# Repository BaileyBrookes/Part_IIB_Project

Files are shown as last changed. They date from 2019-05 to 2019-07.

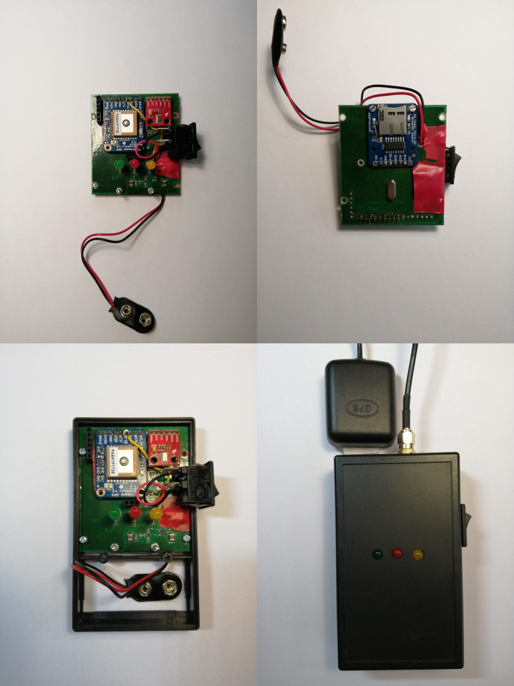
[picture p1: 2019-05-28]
Final Report/Module.png

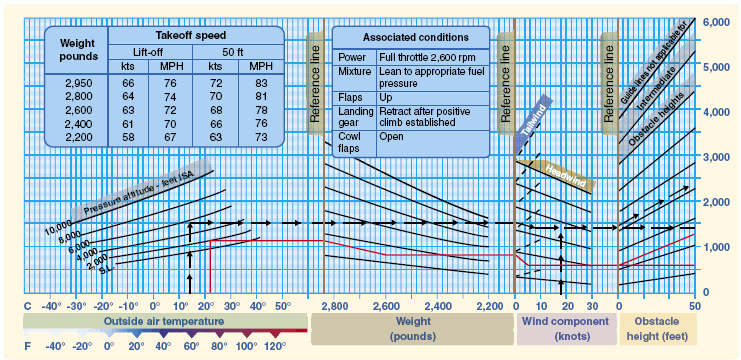
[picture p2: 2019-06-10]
Final Report/Performance_chart.png

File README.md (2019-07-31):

# Part IIB Project: Aircraft Performance Logger:
### Developing a cheap module using GPS and pressure sensor to measure accurately take-off distance required (TODR)
This is the enire project directory, files/folders of note are:

1. AircraftDataLogger - KiCad design files for PCB design

2. \Code\Arduino Sketches\Firmware - Firmware for the PCB

3. Code\TODR.py - Python script that calculates TODR and ground roll

4. Code\CheapDGPS2.py - Script investigating the DGPS idea, with data collected in preliminary testing

Other python scripts have been used in investigation and making plots.

For any clarification or help please email me at bailey.brookes@hotmail.co.uk

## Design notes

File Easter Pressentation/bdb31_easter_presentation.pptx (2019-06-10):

## Aircraft Performance Logger

IIB Project – Easter Presentation

## Problem definition

- Performance characteristics of airplanes:
  - Ground roll
  - Distance to clear 15 m = Take off distance required (TODR)
- Accurate data for safety, creation of performance charts
- Current methods:
  - Expensive DGPS, image processing or laser systems
  - By-eye by test pilots
- Want a cheap module separate from aircraft.

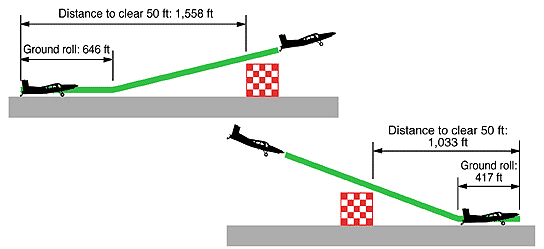
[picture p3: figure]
A close up of text on a white background Description generated with high confidence

Ground roll and TODR definitions

A screenshot of text Description generated with high confidence

Performance chart example

## Project Plan

- Michaelmas – Proof of concept

- Charactise GPS and pressure sensor
- Explore ways to make GPS readings more accurate
- Decide on method of measuring distance and altitude going forward
- Choose method of controlling electronics
- Choose data processing method

- Lent – Design, Build

- Design PCB
- Assembly PCB and module
- Program microcontroller

Easter – Test, Write up

- Testing
  - Static
  - Flight
- Write up

## ‘Cheap’ DGPS

- Errors in readings due to multipath, ionosphere, reflection of signals, etc
- Corrections usually done on signals themselves
- Blue ‘base’ readings, average is true location
- Pair each ‘base’ reading to red ‘roaming’ reading
- Find orange error vector between base reading and average
- Subtract from red roaming to correct it

Longitude

Latitude

## Results: ‘Cheap’ DGPS doesn’t work

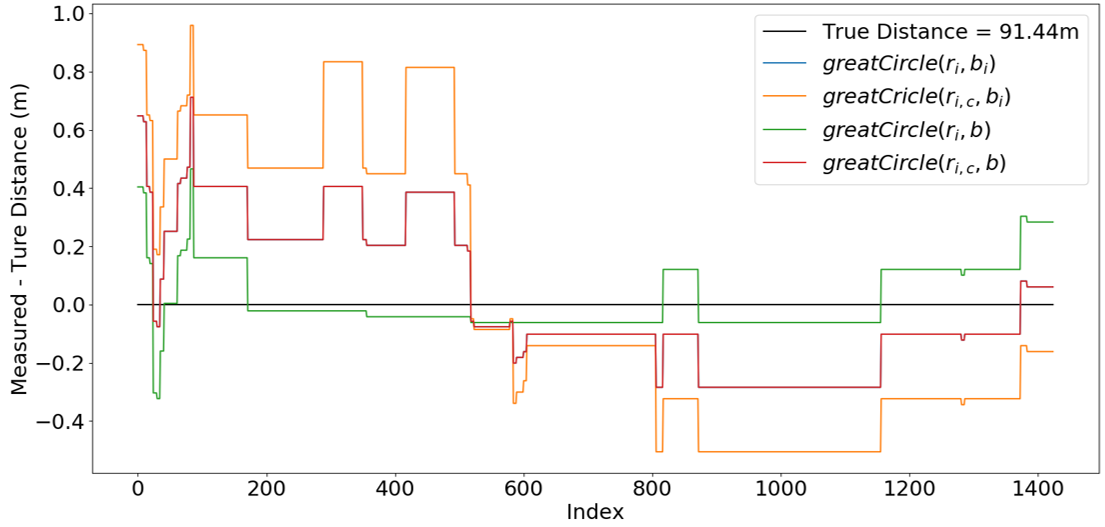
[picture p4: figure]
A close up of a map Description generated with very high confidence

‘100m Test’ True distance = 91.44m | Distance Delta (m) | MSE (m²) | σ (m)
Uncorrected | 1.3602 | 0.0632 | 0.2507
Corrected | 1.3602 | 0.2246 | 0.4734

## Results: The Module

A picture containing wall, indoor Description generated with very high confidence

Final Module

LED

LED

LED

GPS Module

UART

Microcontroller

Pressure Sensor

I2C

Switch

SPI

SD Card

Block diagram of design

## Results: Calculating TODR

1. The run data of distance vs height is plotted.
2. Assuming a linear rate of climb, the line of best fit for the climbing phase is calculated.
3. This line is extended for the entire run (orange line).
4. The average height for the runway is plotted and extended for the length of the whole run (green line).

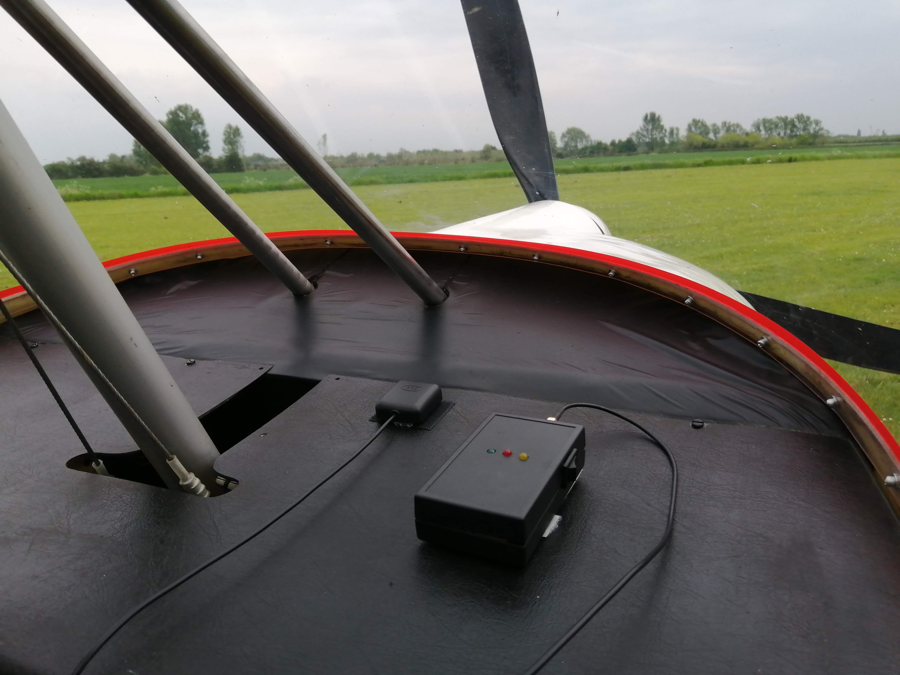
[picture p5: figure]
A small plane sitting on a runway Description generated with very high confidence
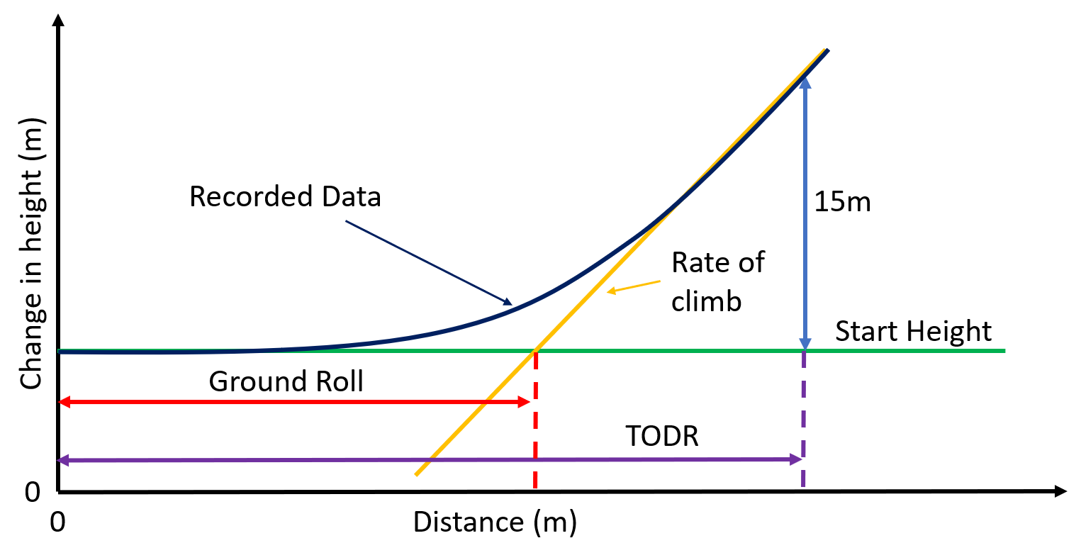
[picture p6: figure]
A picture containing sitting, indoor Description generated with high confidence

## Results: TODR and Ground Roll

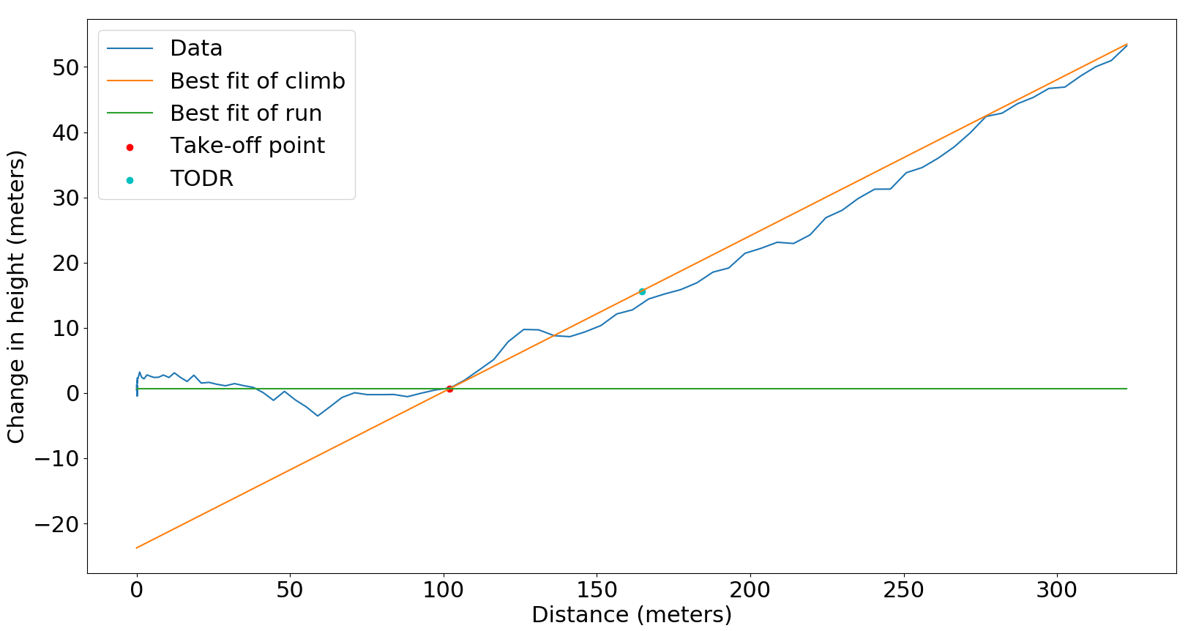
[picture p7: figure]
A close up of a map Description generated with high confidence

3.2m jump

Ground Roll: 101.91m

TODR : 164.58 m

Handbook value : 195 m

## Results: Effect of propeller wash

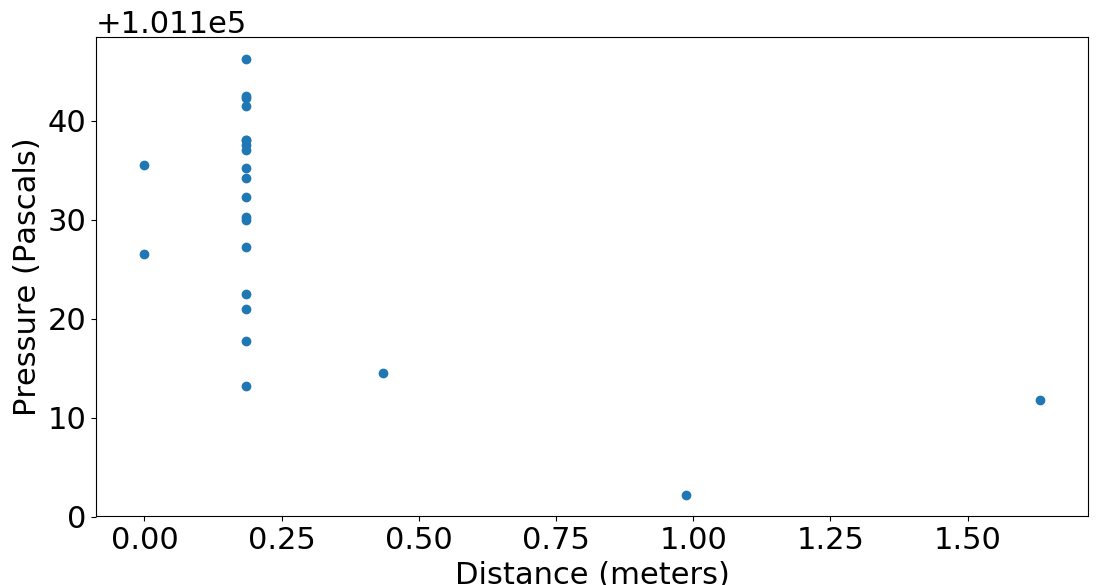
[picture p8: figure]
A screenshot of a cell phone Description generated with very high confidence

(dh)/(dp)=1/(−ρh)=1/(−1.644 ∗9.81)=−0.00875 m/Pa
∆p=33 Pa ∴ ∆h=2.89m ±0.8m

Propeller speed increased as take-off starts
Increased airspeed through propeller means lower pressure
Causes an apparent jump in height

p_1 + 1/2ρv_1^2 = p_2 + 1/2ρv_2^2
p_2 −p_1 = 1/2ρ(v_1^2 −v_2^2 )
v_2 >v_1 ⇒p_2 <p_1

## Conclusions

- ‘Cheap’ DGPS not used as no improvement on accuracy
- Method of calculating TODR sometimes overestimates take off point
- Pressure sensor accuracy less than desired due to
  - Oversampling rate
  - Propeller wash
  - Dynamic effects
- Module, with further development, can measure other parameters, such as landing

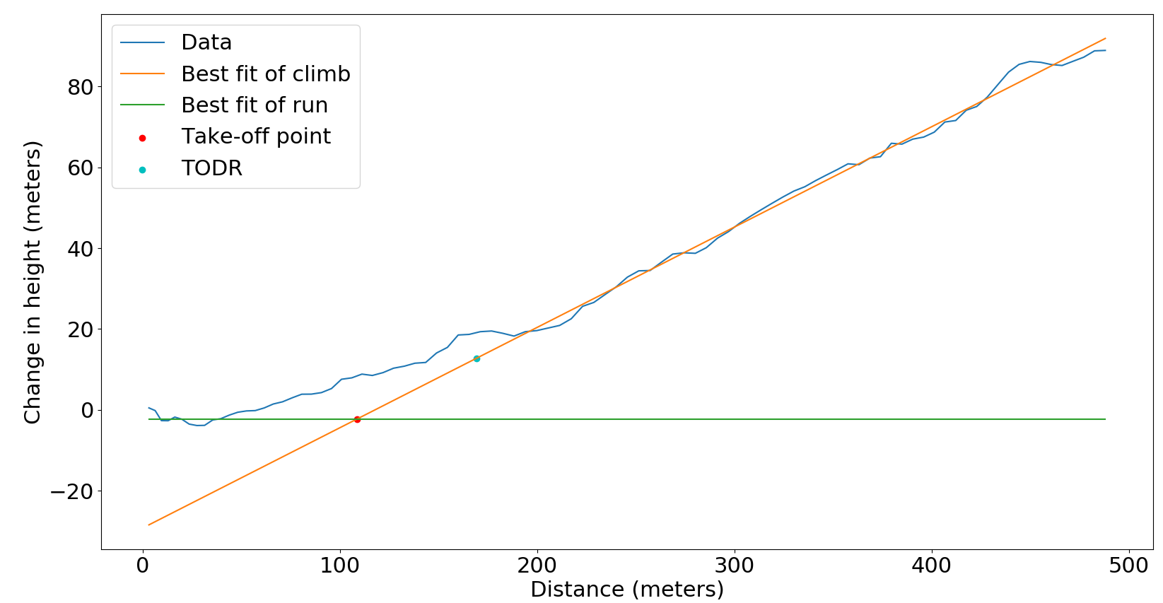
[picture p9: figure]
A close up of a map Description generated with very high confidence
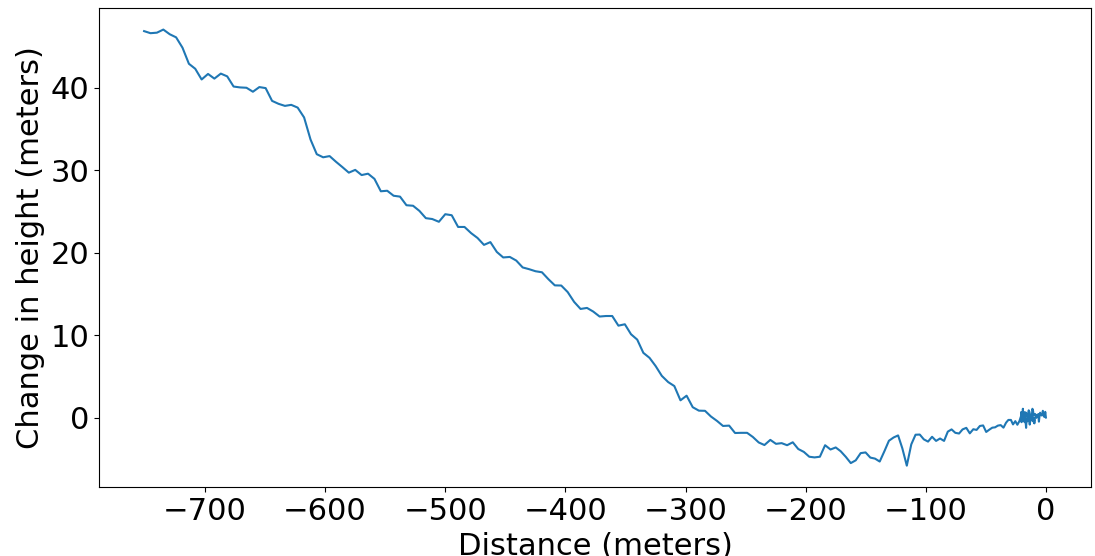
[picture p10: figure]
A screenshot of a cell phone Description generated with very high confidence

## Aircraft Performance Logger

IIB Project – Easter Presentation

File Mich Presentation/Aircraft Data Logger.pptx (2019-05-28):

## Aircraft Data Logger

IIB Project – Michaelmas Presentation

## Can you land here?

London City Airport (LYC): 1,508m

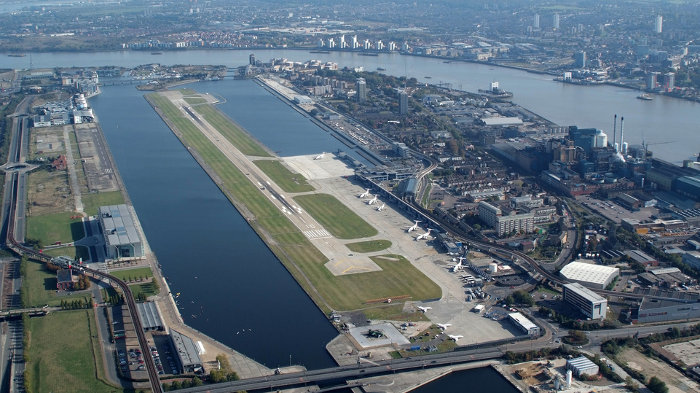
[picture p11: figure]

Barra Airport (BRR): 680,799,846m
- Sand
- Tide

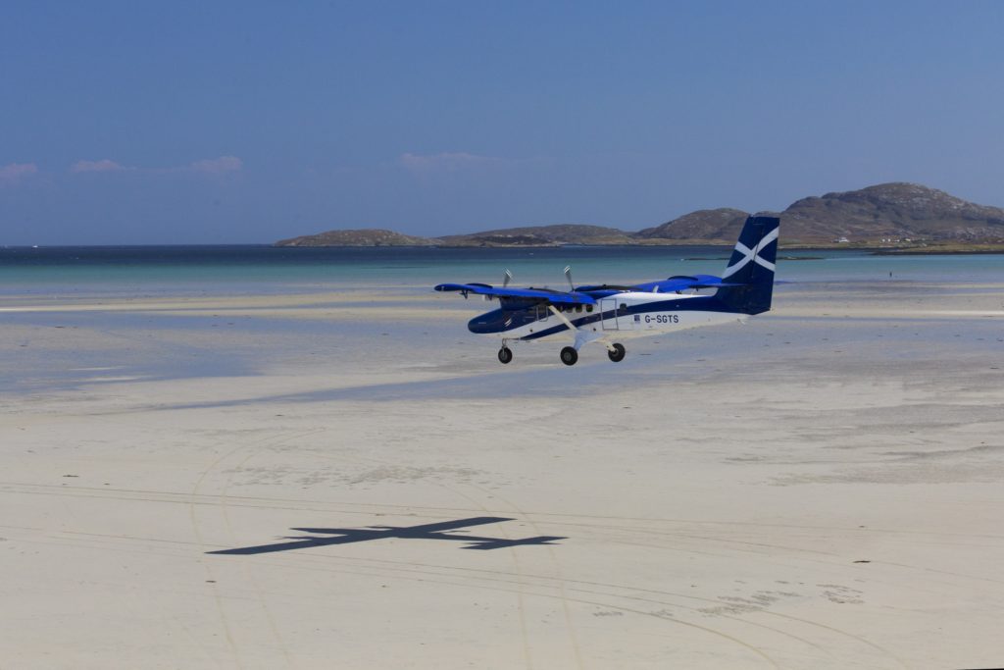
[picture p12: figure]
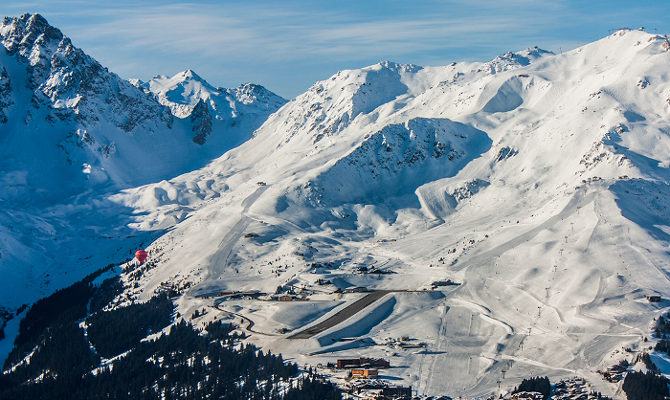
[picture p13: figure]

Courchevel-670 (CVF) : 537m
- At altitude
- Mountains
- 18% gradient

## Take-off and landing parameters

- Paraments we need:
  - Ground Roll – Distance to take off/land
  - Distance to clear 50ft (15.2m) – Get over obstacles, ensure great enough climb rate
- Depend on:
  - Pressure
  - Temperature
  - Weight
  - Windspeed
  - Runway surface etc etc
- Determine from Performance charts or tables:
  - Given conditions, how far do I need?

A close up of text on a white background Description generated with high confidence
A screenshot of text Description generated with high confidence

## Method 1: Calculation

Method
Take all your parameters, conditions
and equations of motion and crunch
through it

Drawbacks
Laborious, time consuming
Model gets more complex the more parameters there are

Advantages
- Simple, cheap
- Can be implemented in software

## Method 2: “By-eye”

Method
Plane has all the instruments, runways
have distance markings, just judge it
while you take off

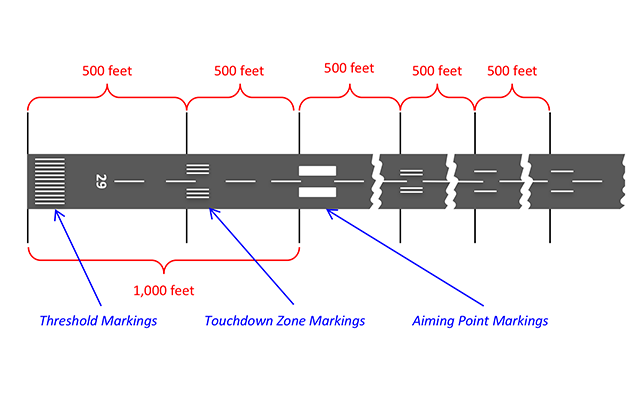
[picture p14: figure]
A close up of text on a white background Description generated with very high confidence

Drawbacks
Not very accurate
Another thing for the test pilot to be worrying about

Advantages
The simplest bar far
No special equipment or complex calculation required

## Method 3: Differential GPS

Method
Using a GPS base station that has a
known, fixed location, correct the errors
from the aircrafts GPS to get a accurate
reading of distance. Use the altimeter
to get distance to clear 50ft.

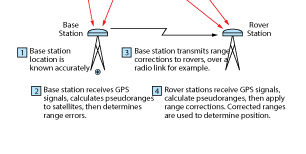
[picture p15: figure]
A close up of a map Description generated with high confidence

Drawbacks
DGPS-capable modules are very expensive

Advantages
Most accurate method
Many airports already have base stations

## Goal of Project

Goal
“Create a cheap module that can measure accurately ground roll, distance to clear 50ft and distance to descend 50ft for aircraft”
Requirements:
1. ~10Hz data acquisition rate
2. Get altitude to within 1ft (30cm)
3. Get distance to within 3ft (1m)
4. Cheap, small, easy to use module
5. Post-processing saved data allowed, but real time results desirable

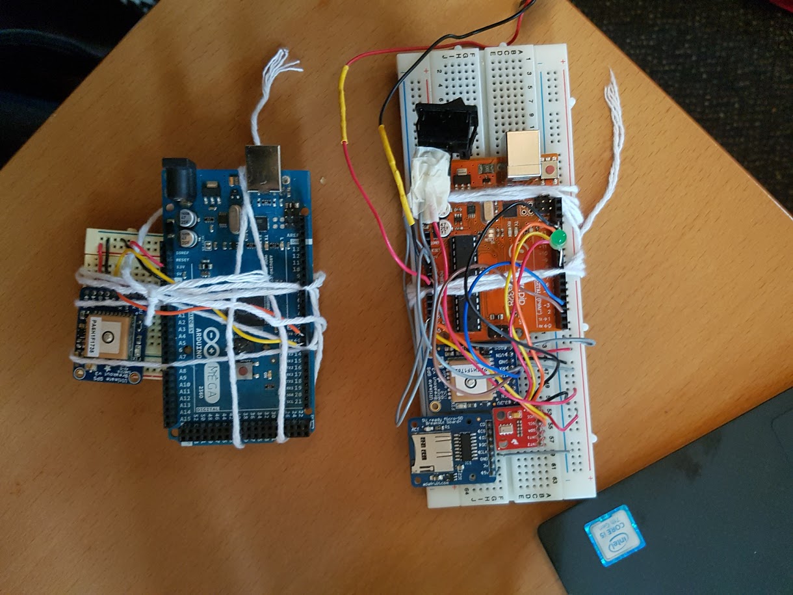
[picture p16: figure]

## Plan

- Michaelmas – Proof of concept

- Characters GPS and pressure sensor
- Explore ways to make GPS readings more accurate
- Decide on method of measuring distance and altitude going forward
- Choose method of controlling electronics
- Choose data processing method

- Lent – Design, Build, Test

- Design PCB
- Assembly PCB and module
- Program microcontroller
- Test module (department aircraft)

Easter – Wrap up

- Further improvements
  - Screen
  - Telemetry
- Report

## Current Progress: Cheap DGPS

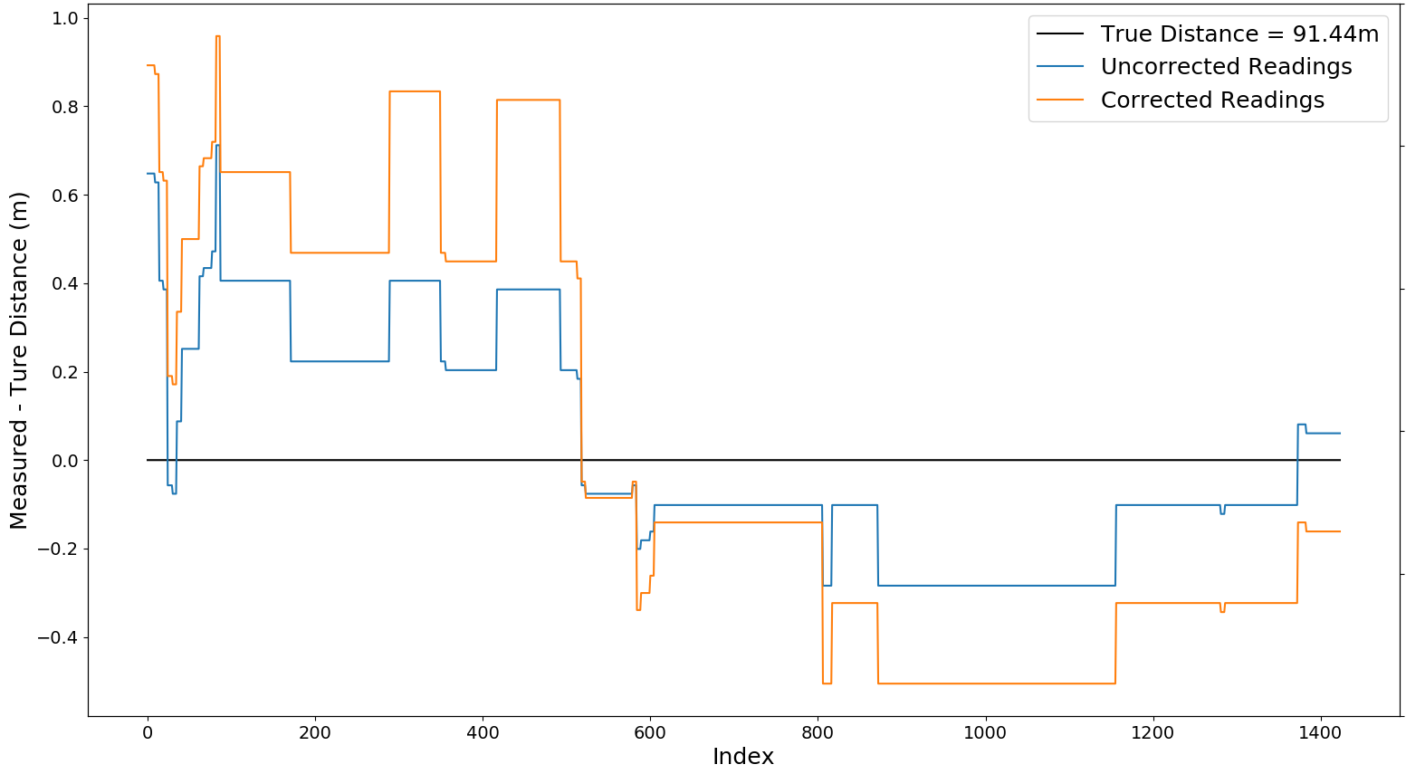
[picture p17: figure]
A screenshot of a video game Description generated with high confidence

‘100m Test’ True distance = 91.44m | Distance Delta (m) | MSE (m²) | σ (m)
Uncorrected | 1.3602 | 0.0632 | 0.2507
Corrected | 1.3602 | 0.2246 | 0.4734

## Current Progress: Cheap DGPS

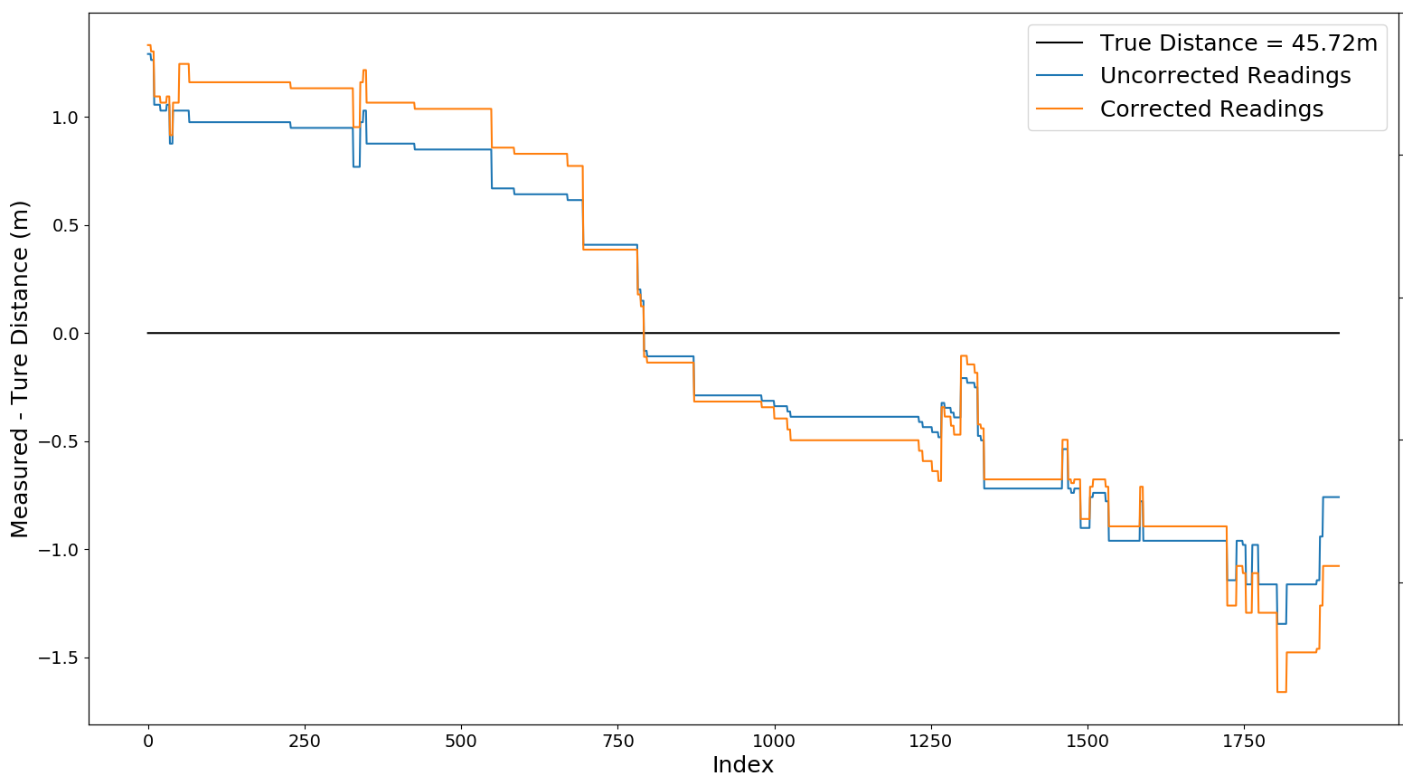
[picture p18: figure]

‘50m Test’ True distance = 45.72m | Distance Delta (m) | MSE (m²) | σ (m)
Uncorrected | 2.8443 | 0.5862 | 0.7652
Corrected | 4.3862 | 0.7576 | 0.8703

## Current Progress: Cheap DGPS

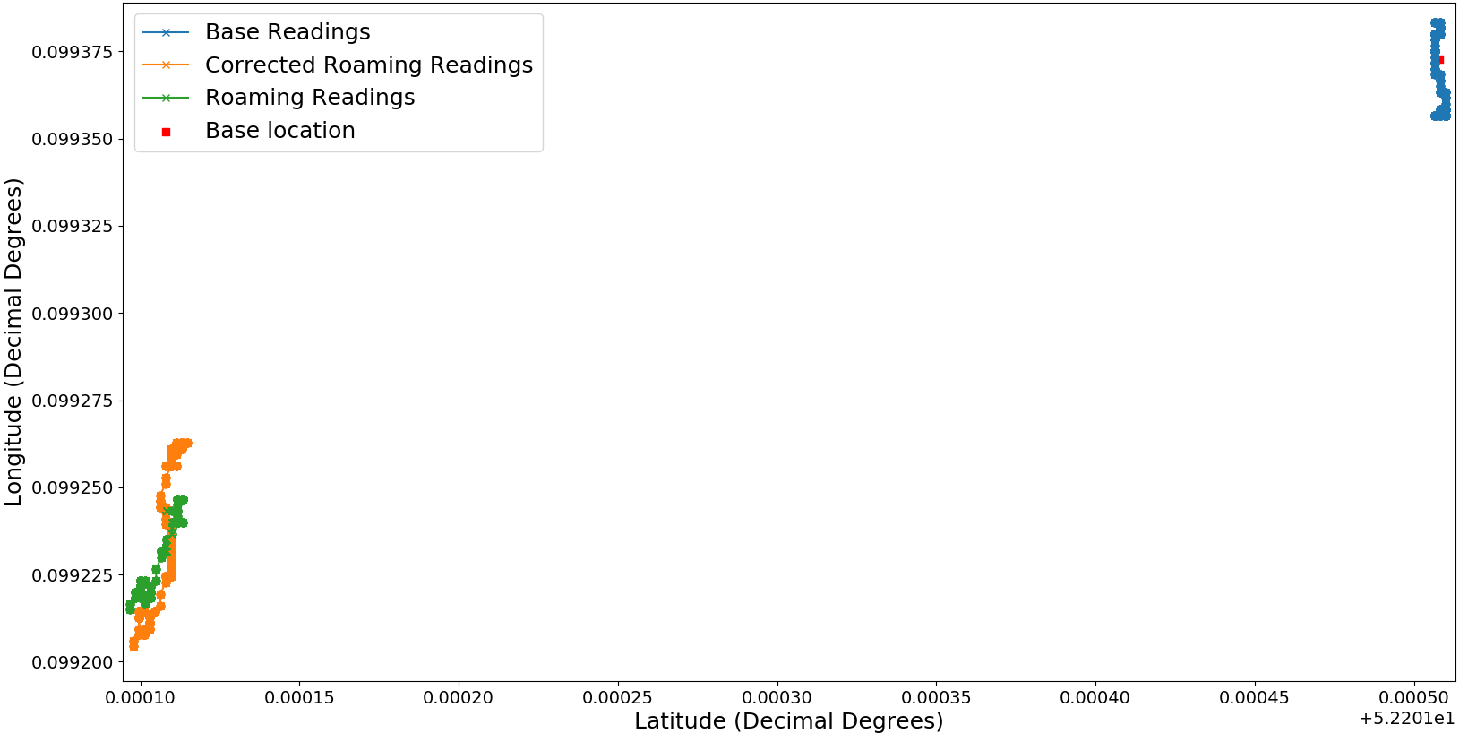
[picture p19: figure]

Average Location

Variation

‘Corrected’ ≈ΣErrors

‘Uncorrected’

Latitude-Longitude plot for the 50m test

## Current Progress: Altitude

Steady vs Temp

Walk about

## Take aways

- DGPS may not be the way to go
  - No drastic improvement
  - Sometimes makes it worse
- Pressure sensor suitable for the roll

Further Work

- Investigate fix vs frequency
- Look at a moving roaming station
- Does satellites in view have an effect?

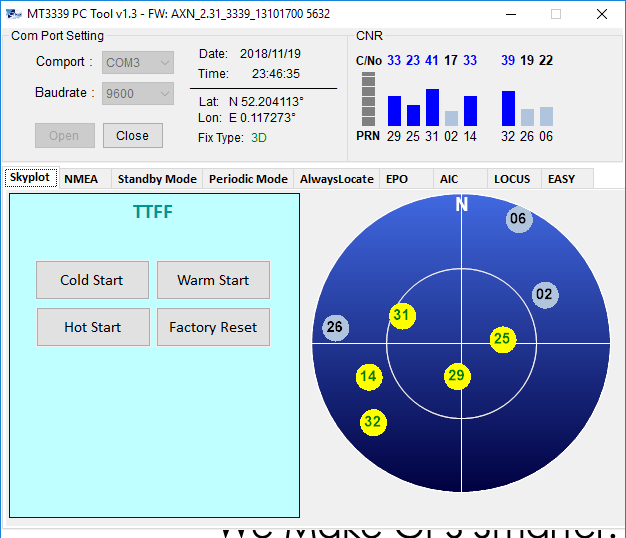
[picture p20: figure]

Uncorrected

Corrected

## Aircraft Data Logger

IIB Project – Michaelmas Presentation

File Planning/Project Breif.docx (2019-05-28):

# Aircraft performance logger

Reference: B-PAR10-2
Supervisor: Dr Paul Robertson
Email Contact: par10@eng.cam.ac.uk
Contact Location: CAPE – 101
Status: approved
Engineering Areas: Electrical and Electronic Engineering, Instrumentation and Control

# Description

A couple of the performance parameters quoted for light aircraft are: the take-off roll (length of runway used to leave the ground) and total distance covered to reach 15 m height (an indicator of what length of runway you need to clear trees at the far end). Both are 'measured' by a test pilot using an element of judgement - and the figures are often not very accurate.

The objective of this project is to develop a 3-d logger unit to be carried in the aircraft which measures distance and height very accurately. Basic GPS cannot do this, as the height indication is not very good (worse than 2-d coordinates). So, the idea would be to include a high accuracy pressure sensor for an altimeter, and to use differential GPS in some way. As flight tests are conducted near the airfield, a base GPS unit with radio telemetry is possible.

So, there are some similarities to the 'electric sheep' project, but the performance parameters are very different: we need say 10 Hz 3-d data to 15 cm resolution. Real-time display would be useful but not essential, post processing when back on the ground is OK (they do this for the other data). Pressure sensing will also be tricky as dynamic pressure due to airspeed will need to be compensated in some way. Flight testing should be possible next year in the Dept.'s hybrid aircraft.

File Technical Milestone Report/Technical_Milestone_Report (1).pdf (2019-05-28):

# Technical Milestone Report - Aircraft Data Logger

### Bailey Brookes | Corpus Christi | bdb31 | 5592G

Abstract

Pilots use aircraft performance charts to calculate take off and landing distance and it is important that these charts are accurate for the pilots safety. Charts are construed from test data and so this test data must also be accurate, but this comes at a cost, especially if using an ‘off the shelf’ solution. In this report, the project plan for an ‘Aircraft Data Logger’ is laid out, showing current progress including researching a cheaper and simpler alternative to Differential GPS.

### 1 Introduction

In order for a pilot to safely take off or land an aircraft, they must know the aircrafts take off distance and distance to clear 15m. Conditions such as ambient temperature, pressure, wind speed, runway surface and gradient and aircraft weight all affect this distance. So pilots can determine this distance, aircraft performance charts are used. Given the weather conditions, runway conditions and aircraft weight, the pilot can read off take off distance form the chart. Constructing these performance charts so there take off distances are accurate is therefore of great importance for the safety of the pilot and others on board an aircraft.

There are well know equations or software that will take test data of take off distance and distance to clear 15m as well as the weather and runway conditions and produce a performance chart by extrapolating from the data. So for the performance chart to be accurate, the test data must be accurate. This however, for light aircraft, isn’t the case. Test pilots acquire this data ‘by eye’, using markers on the runway and the aircraft’s altitude meters to try and determine these distances. This method is prone to human errors due to the test pilot also trying to operate the aircraft at the same time and runway distance markers may be incorrect.

Accuracy is obtained in commercial aircraft testing by several methods, including using a Differential Global Position System (DGPS) solution, which has cm accuracy in surveying use. These however are expensive, with an ‘off the shelf’ DGPS staring at around £500, meaning test pilots either not being able to afford them for testing light aircraft, or think that the gain in accuracy is not worth the cost. Furthermore, the determination of altitude using GPS results in significantly less accurate results when compared to results of altimeter. There is therefore a need for a cheap but accurate method of collecting test data to construct aircraft performance charts. This is the goal of this project.

### 2 Background

### 2.1 GPS

A GPS receiver uses the location of at least 4 satellites and the time it takes for each signal to reach the receiver to compute a receivers location using trilateration. With timing being the crucial component to accurate location, any error or delay in this signal will result in an inaccurate or incorrect location. A main source of errors is propagation errors, which are introduced as the signal slows as it passes through the ionosphere (caused by ionized particles slowing the signal down) and troposphere (caused by changing refractive index). Deviations in satellite behaviour, including incorrect potion and number of satellites visable, also affect the accuracy of the position.

### 2.2 Differential Global Positioning System (DGPS)

To overcome the error in position due to signal delay, DGPS can be used. This involves two receivers, a base receiver at a fixed, known position, and a roaming receiver.

Over time propagation errors average out to zero as they are random. So if a receiver doesn’t move, its average location will be correct. So when a delayed signal is received a from satellite, it knows what the signal should be instead so calculates the difference between the delayed signal and the signal it should have received from this satellite. This error for this satellite is then transmitted to a roamer station which can then correct the signal it gets from this satellite. By doing this for all the satellites both receivers see and then using these corrected signals for the position calculation, error from propagation delay can be removed. This greatly increase the accuracy from 3m to a few centimeters for surveying grade DGPS.

### 3 Project Goal

The goal of the project is to create a cheap module that can measure accurately take off distance, distance to clear 15m and distance to descend 15m for aircraft.

Such a module has to meet the following requirements:

- 10Hz data acquisition rate: To allow a high enough resolution to determine take off and 15m so distances can be calculated.
- Altitude accurate to within 0.3m: At 15m, this is an error of 2% which is has been deemed acceptable as it is relatively small.
- Distance accurate to within 2m: Take-off instances range from between 1500m to 2000m, meaning an error of around 0.1%, which is less then the ‘by eye’ approach and is a small enough error to be acceptable.
- Standalone module: Can be taken from aircraft to aircraft, and also have an external antenna plugged in so it has a clear line of sight with the sky.
- Removable memory: This allows for the data to be post processed by some software.

- Easy to use: This includes things such as 2 status LEDs to ensure the user knows if the GPS has a fix and if the module is logging, and the post processing being ‘plug and play’, meaning only the SD card needs interesting and a simple process followed to get results.

And the end of this project, the solution will be assessed against these requirements to evaluate the project.

### 4 Project Timeline

The project is broadly split into 3 parts:

- Research phase: During Michaelmas term, investigating hardware to be used and assessing their suitability was key. DGPS alternatives where investigated. Decision where then made on if DGPS is needed as well as the architecture of the data logger.
- Design and make phase: This is where the PCB for the module is designed and fabricated, the casing designed, firmware written and post processing code written. This is to be done in Lent term.
- Test and reporting phase. A testing plan will be drawn up and testing will hopefully take place using the engineering departments aircraft. The entire project will then be written up. This takes place at the end of Lent term as well as during Easter term.

I’ve chosen not to plan the project in the form of a Gantt chart as with some aspects of the project being new to me, such as ECAD design and writing firmware from scratch, means I don’t know how long they will take. Also, testing will be ongoing as features are added to the module. Instead, the rest of the project is planned in a series of milestones to reach:

- Milestone 1: Decide on PCB architecture.
- Milestone 2: Send PCB off to be fabricated. This means it must be designed as well.
- Milestone 3: Write completed firmware for the module, so it reads GPS and pressure sensor data and save the data to the SD card
- Milestone 4: Get take-off distance and distance to clear 15m from via post processing the data.
- Milestone 5: Successful testing of the module.

### 5 Current Progress

### 5.1 GPS

The MTK3339 GPS mould was chosen at it has 10Hz data acquisition rate, comes in a breakout board package, and outputs NMEA sentence via UART. This allowed for quick set up and prototyping through connecting it to an Arduino, allowing for an alternative DGPS to be experimented with.

### 5.1.1 Investigating DGPS alternatives

Conventional DGPS removes the error caused by propagation delays before calculating position. However, if two GPS modules are close enough together they should see the same section of sky, so see similar satellites and have similar propagation delay errors. Therefore the error in their position calculations should be similar so instead of using the signal error, by averaging the base location over time and using the difference in location of a reading at time t and the average base location as the error and communicating this to the roaming receiver, it can subtract this error from its location which should improve the accuracy of the reading. This is the method behind our ‘cheap’ DGPS.

To test this method of correcting GPS readings, 2 modules where placed at a fixed distance apart for a length of time. One module was used as the base module, with readings denoted bi

, and its average location was calculated (b). Then each roaming station reading (ri) was matched to the base location reading taken at the same time (bi). The difference in average base location and measured base location (ei = bi − b) was then subtracted from the roaming reading to create a corrected roaming reading (ri,c = ri − ei). The great circle distance between any two readings can then be calculated.

Figure 1 shows a plot of the great circle distance between two points minus the true distance apart (91.44m due to the length of the rugby pitch) plotted over time.


Figure 1: Plot of the error in distance between two points over time. bi represents a base module reading and b the average base location reading.ri represents a raw, uncorrected roaming station reading while ri,c a corrected roaming reading

Interestingly, the distance between uncorrected base (bi) and roaming (ri) readings (blue line, not visable) is the same as the distance between the average base location (b) and corrected roaming (ri,c) readings (red line, on top of blue line). This makes sense as by subtracting the error vector ei

from both (bi) and (ri), the distance between the two points has not changed as ei

is parallel to itself.

One thing that does improve the accuracy and removes large jumps in readings is by using the average base location (b) and the uncorrected roaming readings (ri), as this removes the variation in the base location. Of course this could be further improved by averaging the roaming receiver location but this would be counter productive when the roaming receiver starts to move, such as when taking off. However, if we average the location of the module when sat still before taking off, we can use that average location the measure distances from, which should improve the distance accuracy. This is one of the next things to test.

Furthermore, the GPS module being used comes with Satellite-Based Augmentation System (SBAS) enabled which delivers to the module the corrections and integrity data as well as some ancillary information (timing, degradation parameters, etc.) through messages encoded in the signal. The GPS module can use this information to correct signals and position much like DGPS and this is enabled on the MTK3339 by default. So if corrections have already been made to the signal, this further correction post processing is not only unnecessary, but may be introducing error due to different satellites being in view for each module or multipath errors, resulting in a worse reading.

### 5.1.2 Data acquisition rate

In this test, the GPS module was placed stationary in a field, got a location fix and logged data for 10 minutes. Table 1 shows the mean and standard deviation in latitude and longitude as well as the maximum variation in distance at each frequency.

Statistic | 1Hz 5Hz 10Hz
µlat(decimal degrees) µlon(decimal degrees) σlat(×10⁻⁶ ) σlon(×10⁻⁶ ) δd(m) | 52.201457 52.201462 52.201493 0.0993762 0.0993744 0.0993608 2.610 3.985 7.020 3.363 3.834 0.9329 1.44 1.68 2.60

Table 1: Results of the data acquisition rate test, showing standard deviation in latitude, longitude and greatest distance between two points

As the table shows, the 1Hz and 5Hz agree well, having similar variation and position. At 10Hz however, there is a larger variation and the location doesn’t agree. This is because the SBAS (described above) is disabled above 5Hz, even if the NMEA sentence says it is active. Without SBAS, the datasheet claims the position accuracy drop from 2.5m to 3m. This explains the greater variation in position and the shift in position, as the GPS module isn’t making the signal corrects as it hasn’t received the data to do so. This means there is a trade off of having a high data acquisition rate for greater resolution when moving at take off speed, or a lower acquisition rate to ensure better accuracy in position.

### 5.2 Pressure Sensor

The MPL3115A2 pressure sensor has been chosen for altitude measurement as it fulfills the requirements over having a 10Hz data acquisition when in polling mode, and gives altitude accurate to 0.3m.

During testing it was found that temperature effects the pressure reading, as well as wind speed and other effects, such as being inside or outside. To avoid fluctuations when the pressure sensor is used to measure altitude, it will be key to keep the pressure sensor in a controlled environment.

### 6 Conclusions and next steps

So far in the project, the research portion is coming to and end and the design is beginning. From the research we have concluded:

- The ‘cheap’ DGPS doesn’t increase the accuracy of positioning as subtracting either adds error (in the greatCircle(ri,c, bi) case) or makes no difference (in the greatCircle(ri,c, b) case). Furthermore, any increase in accuracy isn’t sufficient enough to warrant the design of another module, so ‘cheap’ DGPS will not be used.
- While the GPS module can operate at 10Hz, the SBAS correction that it can do to improve accuracy can only operate up to 5Hz. Therefore operating at 10Hz decreases the accuracy of the module but does increase the resolution of the data. This trade off needs to be considered.
- As the pressure sensor warms up or the ambient air changes temperature, the changes the pressure reading. Also other conditions such as wind affect pressure readings. So the pressure sensor on the device will need to be isolated to try and keep it at a constant temperature and shield it from wind in order to measure the true ambient pressure.

The next steps in the project are:

- The trade off between accuracy at 5Hz using SBAS and resolution at 10Hz needs to be considered.
- The idea of averaging the location of a stationary aircraft before take off in order to improve accuracy needs to be tested.
- The architecture of the PCB needs to be finalized including choice of micro-controller, power supply and method of attaching the sensors.
- As this a stand alone module, considering the packaging of the module is also key.

### 7 References

1. Errors in GPS: https://www.radio-electronics.com/info/satellite/gps/accuracy-errorsprecision.php
2. How DGPS works: https://racelogic.support/01VBOX_Automotive/01General_Information/Knowledge_Base/How_does_DGPS_(Differential_GPS)_work%3F
3. SBAS fundamentals: https://gssc.esa.int/navipedia/index.php/SBAS_Fundamentals.
4. Data and code for project: https://github.com/BaileyBrookes/IIB-Project

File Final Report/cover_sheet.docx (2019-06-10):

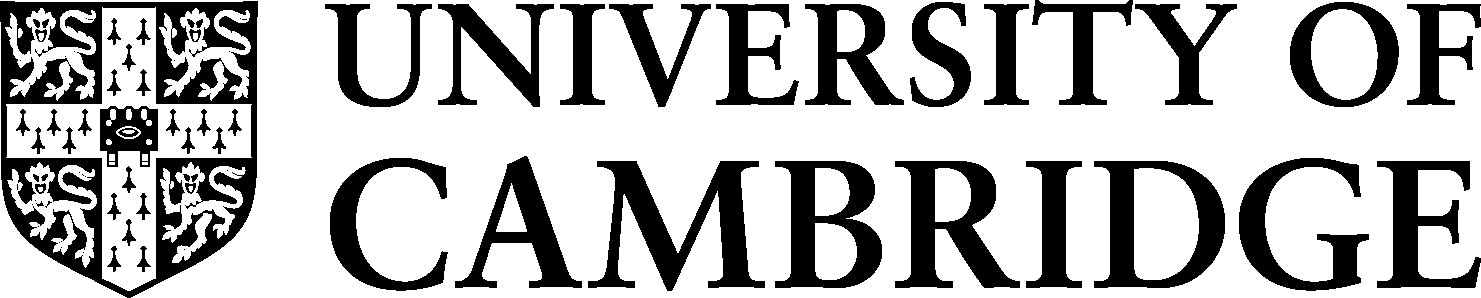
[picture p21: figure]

# Department of Engineering

Aircraft Performance Logger

Author Name: Bailey Brookes

Supervisor: Dr P.A Robertson

Date: 29/05/2019

I hereby declare that, except where specifically indicated, the work submitted herin is my own original work.

Signed _______________________________ date _____________________________

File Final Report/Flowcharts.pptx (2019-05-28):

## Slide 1

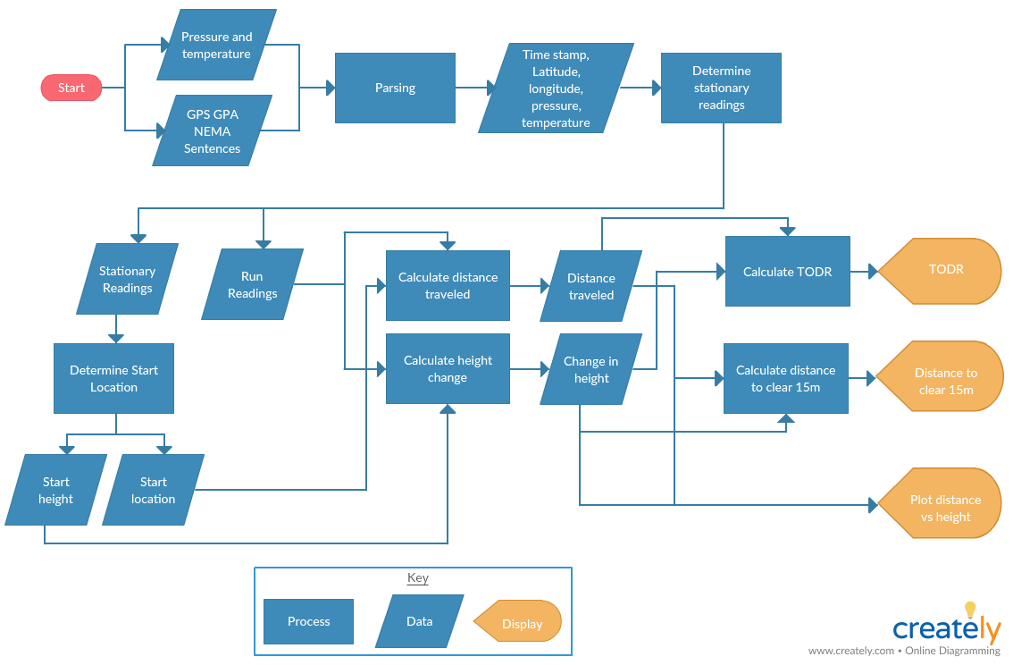
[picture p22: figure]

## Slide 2

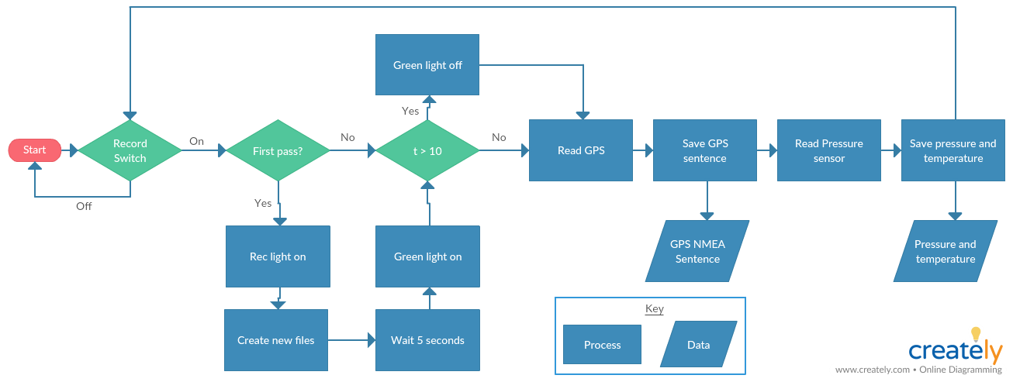
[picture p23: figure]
A picture containing sky Description generated with high confidence

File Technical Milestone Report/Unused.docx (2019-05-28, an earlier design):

For clarity, the following notation will be used:

\begin{center}

$\bold{b_i}$ is a base GPS reading, $[latitude, longitude]$, with a set of reading denoted as

$\bold{B} = [\bold{b_1} ... \bold{b_n}]^\bold{T}$

$\bold{r_i}$ is a base GPS reading, $[latitude, longitude]$, with a set of reading denoted as

$\bold{R} = [\bold{r_1} ... \bold{r_n}]^\bold{T}$

$\bold{\overline{b}}$ is the average base location, $[\overline{latitude}, \overline{longitude}]$

$\bold{e_i}$ is the difference between the base reading $\bold{b_i}$ and the average base location, $\bold{\overline{b}}$ : $\bold{e_i} = \bold{b_i} - \bold{\overline{b}}$

$\bold{r_{i,c}}$ is a corrected roaming reading $\bold{r_{i,c}} = \bold{r_i} - \bold{\overline{e_i}}$

$u_i$ is the great circle distance between the average base location, $\bold{\overline{b}}$ and an uncorrected roaming reading $\bold{r_i}$. This can also be denoted as $greatCircle(r_i, \overline{b})$

$c_i$ is the great circle distance between the average base location, $\bold{\overline{b}}$ and a corrected roaming reading $\bold{r_{i,c}}$

\end{center}

\subsubsection{Internal altitude calculation}

In order for altitude to be calculated, the Barometric input register must be programmed with the test conditions ambient pressure, either at sea level for the absolute altitude, or the pressure on the runway to measure relative altitude. If the project is adapted to include a real time display, this register would have be be programmed to get true altitude, which adds complexity as some input method would have to be made. However, by knowing the difference between air pressure at ground level and 15m or by waiting for the altitude, no matter what the value, to change by 15m, this complexity can be avoided.

In order to get a receivers location using GPS, 4 satellites must be in line of sight of it. These satellites have atomic clocks on board and this time, as well as the location of the satellite in space, is transmitted using radio-waves. When picked up by the receiver, it compares the received time to its internal time and the difference is the time it took to for the signal to reach the receiver. Knowing that the signal travels at the speed of light, the distance from the satellites can be calculated and the knowing the distance to 3 satellites can give location in 2D using trilateration. 4 satellites allow altitude to also be calculated.

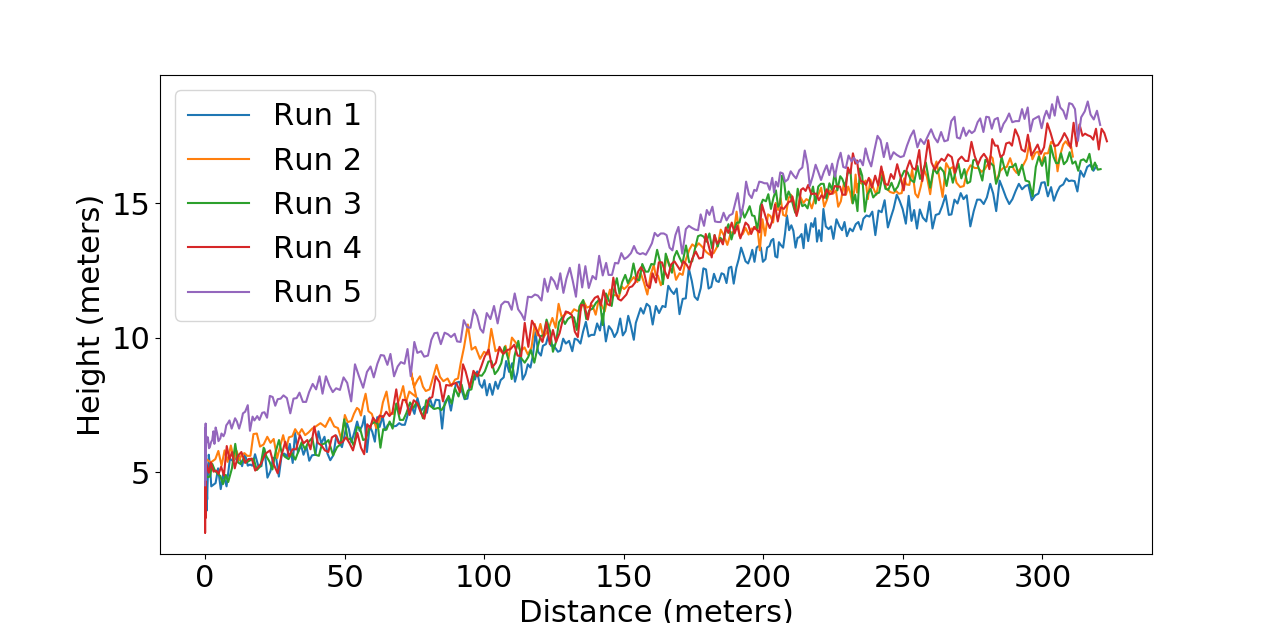
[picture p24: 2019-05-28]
Final Report/Castle_hill_unsmooth_delta.png

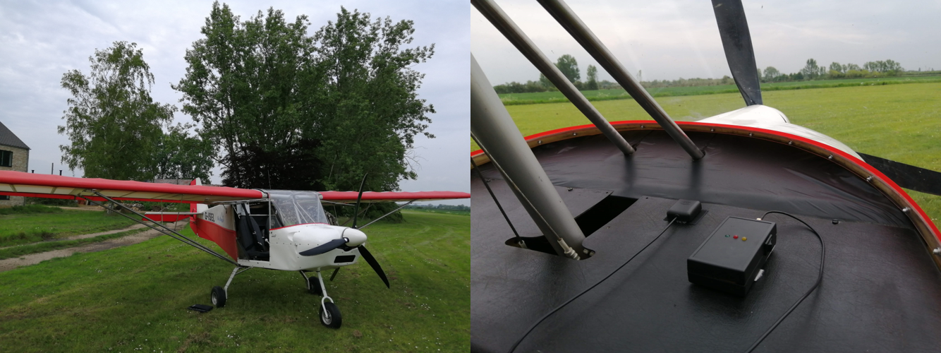
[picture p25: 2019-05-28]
Final Report/Plane.png

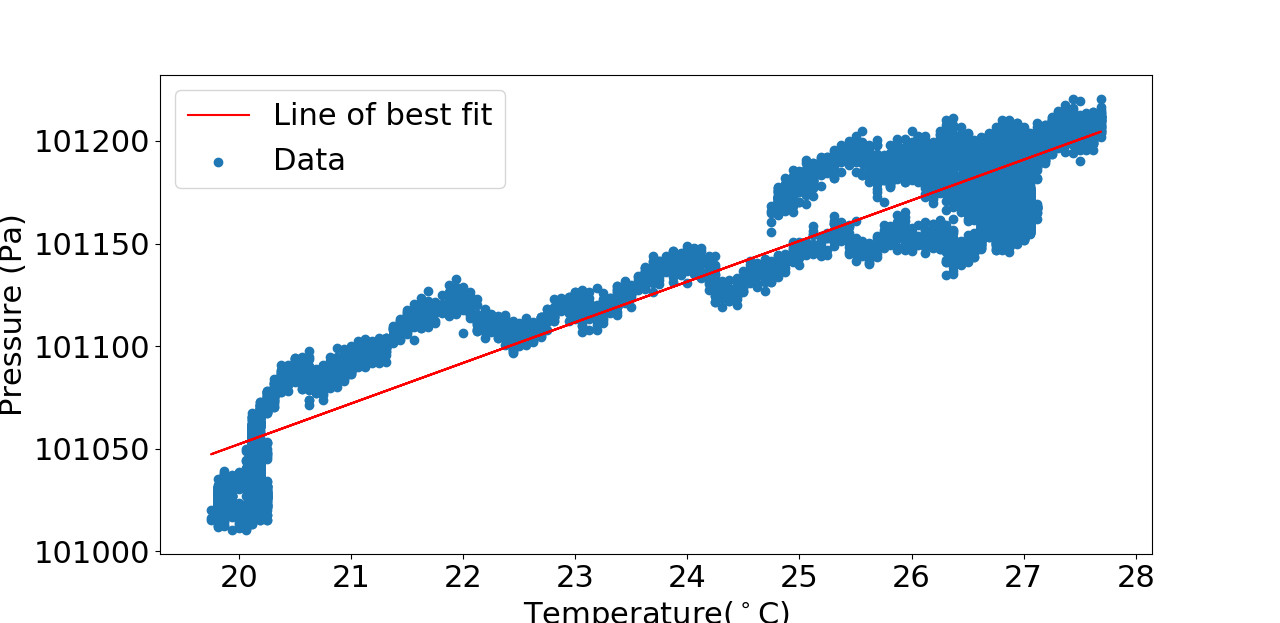
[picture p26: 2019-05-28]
Final Report/Pres_vs_temp.png

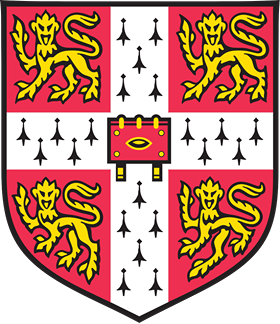
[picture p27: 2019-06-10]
Final Report/49464918_539825453194303_668087054860550144_n.png

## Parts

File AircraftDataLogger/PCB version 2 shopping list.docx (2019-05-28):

# PCB version 2 shopping list

# Passives needed:

22pF capacitors, 0804(2012 Metric)

300kohm resistor, 0804(2012 Metric)

# Things to buy:

Part Number | Description | Link | Cost
HC49S-16-30-50-70-30-ATF | HC49S-16-30-50-70-30-ATF - Crystal, 16 MHz, Through Hole, 10.9mm x 4.65mm, 50 ppm, 30 pF, 30 ppm, HC49S Series | https://uk.farnell.com/multicomp/hc49s-16-30-50-70-30-atf/crystal-hc-49-s-16-0mhz/dp/1667003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 | £0.7764
ADP7118AUJZ-R2 | Analog Devices ADP7118AUJZ-R2, LDO Regulator, 200mA Adjustable, 1.2 → 5 V, ±0.8% 5-Pin, TSOT | https://uk.rs-online.com/web/p/low-dropout-voltage-regulators/8652252/ | £2.778
A6S2104H | A6S2104H - DIP / SIP Switch, 2 Circuits, Slide, SMD, SPST, 24 VDC, 25 mA | https://uk.farnell.com/omron/a6s2104h/switch-dip-raised-actuator-2-way/dp/1960894 | £1.1784
ATMEGA328P-AU | ATMEGA328P-AU - 8 Bit MCU, AVR ATmega Family ATmega328 Series Microcontrollers, 20 MHz, 32 KB, 2 KB, 32 Pins, TQFP | https://uk.farnell.com/microchip/atmega328p-au/mcu-8bit-atmega-20mhz-tqfp-32/dp/1715486?st=ATmega328 | £1.42
Total | | | £6.16

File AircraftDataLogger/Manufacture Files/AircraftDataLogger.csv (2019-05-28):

Reference | Value | Footprint | Notes
D3 | LED | LED_THT:LED_D3.0mm_Clear | Not supplied
D2 | LED | LED_THT:LED_D3.0mm_Clear | Not supplied
D1 | LED | LED_THT:LED_D3.0mm_Clear | Not supplied
C1 | 20pF | Capacitor_SMD:C_0805_2012Metric | Use 22pF
C2 | 20pF | Capacitor_SMD:C_0805_2012Metric | Use 22pF
R1 | 10K | Resistor_SMD:R_0805_2012Metric | Supplied
Y1 | Crystal | Crystal:Crystal_HC49-4H_Vertical | Supplied
U4 | ATmega328PB-AU | Package_QFP:TQFP-32_7x7mm_P0.8mm | Supplied
U1 | ADP7118 | Package_TO_SOT_SMD:TSOT-23-5 | Supplied
C3 | 2.2uF | Capacitor_SMD:C_1210_3225Metric | Use supplied 10uF
C4 | 2.2uF | Capacitor_SMD:C_1210_3225Metric | Use supplied 10uF
R2 | 300 | Resistor_SMD:R_0805_2012Metric | Use supplied 10uF
J3 | Conn_01x02_Female | Connector_PinSocket_2.54mm:PinSocket_1x02_P2.54mm_Vertical | DO NOT SOLDER TO BOARD
J1 | Conn_01x08_Female | Connector_PinSocket_2.54mm:PinSocket_1x08_P2.54mm_Vertical | DO NOT SOLDER TO BOARD
R3 | 300 | Resistor_SMD:R_0805_2012Metric | Supplied
R4 | 300 | Resistor_SMD:R_0805_2012Metric | Supplied
J2 | Conn_01x16_Female | Connector_PinSocket_2.54mm:PinSocket_1x16_P2.54mm_Vertical | DO NOT SOLDER TO BOARD
J4 | Conn_01x02_Female | Connector_JST:JST_PH_B2B-PH-SM4-TB_1x02-1MP_P2.00mm_Vertical | DO NOT SOLDER TO BOARD
R5 | 280k | Resistor_SMD:R_0805_2012Metric | Not supplied
R6 | 160k | Resistor_SMD:R_0805_2012Metric | Not supplied
R7 | 1.6k | Resistor_SMD:R_0805_2012Metric | Not supplied
C5 | 33nF | Capacitor_SMD:C_0805_2012Metric | Not supplied
SW2 | SW_SPDT | Button_Switch_SMD:SW_SPDT_CK-JS102011SAQN | Supplied
J5 | Conn_01x02_Female | Connector_JST:JST_PH_B2B-PH-SM4-TB_1x02-1MP_P2.00mm_Vertical | DO NOT SOLDER TO BOARD

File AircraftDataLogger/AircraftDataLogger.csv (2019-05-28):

Reference | Value | Footprint | Datasheet
D3 | LED | LED_THT:LED_D3.0mm_Clear | ~
D2 | LED | LED_THT:LED_D3.0mm_Clear | ~
D1 | LED | LED_THT:LED_D3.0mm_Clear | ~
C1 | 22pF | Capacitor_SMD:C_0805_2012Metric | ~
C2 | 22pF | Capacitor_SMD:C_0805_2012Metric | ~
R1 | 10K | Resistor_SMD:R_0805_2012Metric | ~
Y1 | Crystal | Crystal:Crystal_HC49-4H_Vertical | ~
U4 | ATmega328PB-AU | Package_QFP:TQFP-32_7x7mm_P0.8mm | http://ww1.microchip.com/downloads/en/DeviceDoc/40001906C.pdf
U1 | ADP7118 | Package_TO_SOT_SMD:TSOT-23-5
C3 | 10uF | Capacitor_SMD:C_1210_3225Metric | ~
C4 | 10uF | Capacitor_SMD:C_1210_3225Metric | ~
R2 | 200 | Resistor_SMD:R_0805_2012Metric | ~
J1 | Conn_01x08_Female | Connector_PinSocket_2.54mm:PinSocket_1x08_P2.54mm_Vertical | ~
R3 | 200 | Resistor_SMD:R_0805_2012Metric | ~
R4 | 200 | Resistor_SMD:R_0805_2012Metric | ~
J2 | Conn_01x16_Female | Connector_PinSocket_2.54mm:PinSocket_1x16_P2.54mm_Vertical | ~
J4 | Conn_01x02_Female | Connector_PinSocket_2.54mm:PinSocket_1x02_P2.54mm_Vertical | ~
R5 | 68k | Resistor_SMD:R_0805_2012Metric | ~
R6 | 39k | Resistor_SMD:R_0805_2012Metric | ~
R7 | 1.6k | Resistor_SMD:R_0805_2012Metric | ~
C5 | 33nF | Capacitor_SMD:C_0805_2012Metric | ~
J5 | Conn_01x02_Female | Connector_PinSocket_2.54mm:PinSocket_1x02_P2.54mm_Vertical | ~
J6 | Conn_01x03_Female | Connector_PinSocket_2.54mm:PinSocket_1x03_P2.54mm_Vertical | ~
J3 | Conn_01x06_Female | Connector_PinSocket_2.54mm:PinSocket_1x06_P2.54mm_Vertical | ~

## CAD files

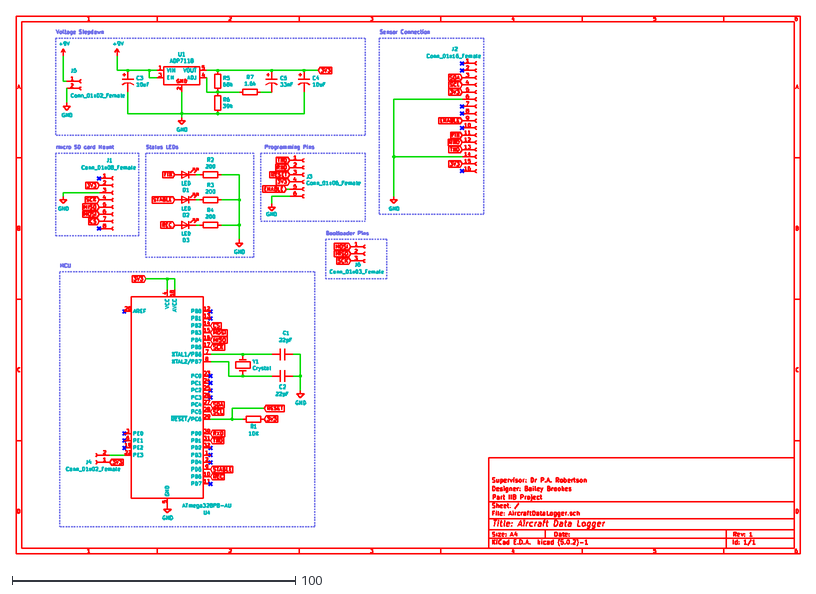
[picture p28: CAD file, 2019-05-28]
AircraftDataLogger/AircraftDataLogger.dxf
277.0 x 190.0

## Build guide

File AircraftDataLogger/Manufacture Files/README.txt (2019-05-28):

PCB Size:56.30mmx64mm

Component Mapping
Some compnets have been provided to be soldered on, some are missing, the supplied BOM shows more

Special Instructions:
DO NOT add pin headers where shown, the holes are being used to directly mount breakout board pins

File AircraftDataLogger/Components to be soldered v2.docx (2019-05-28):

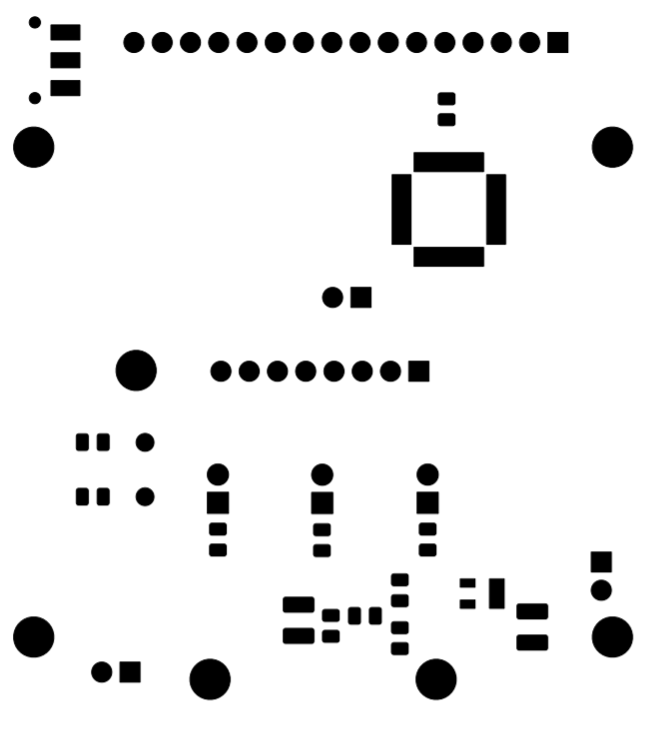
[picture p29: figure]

# Components to be soldered v2

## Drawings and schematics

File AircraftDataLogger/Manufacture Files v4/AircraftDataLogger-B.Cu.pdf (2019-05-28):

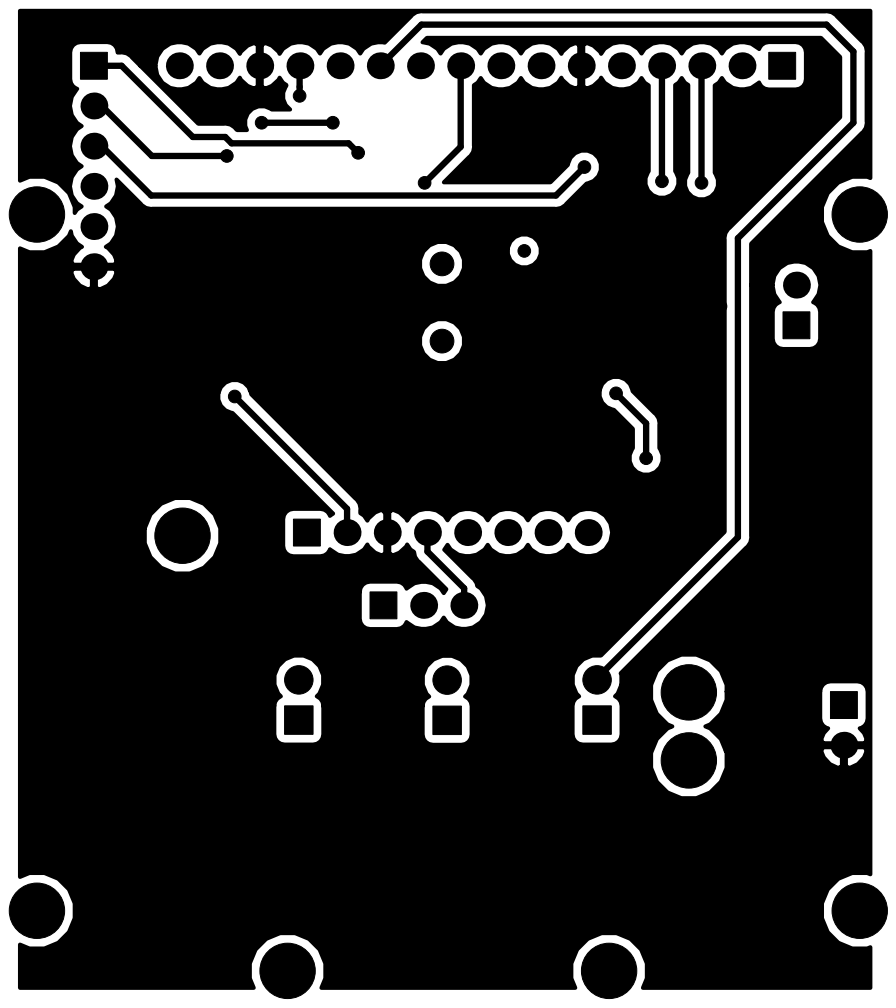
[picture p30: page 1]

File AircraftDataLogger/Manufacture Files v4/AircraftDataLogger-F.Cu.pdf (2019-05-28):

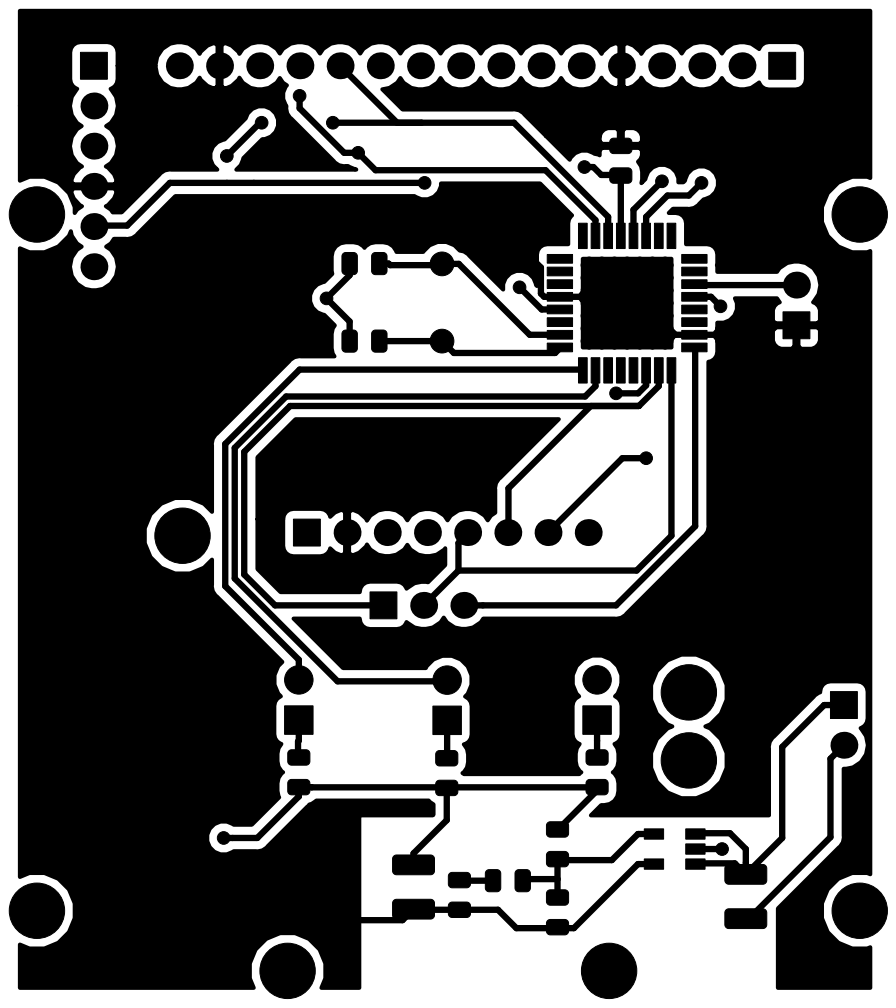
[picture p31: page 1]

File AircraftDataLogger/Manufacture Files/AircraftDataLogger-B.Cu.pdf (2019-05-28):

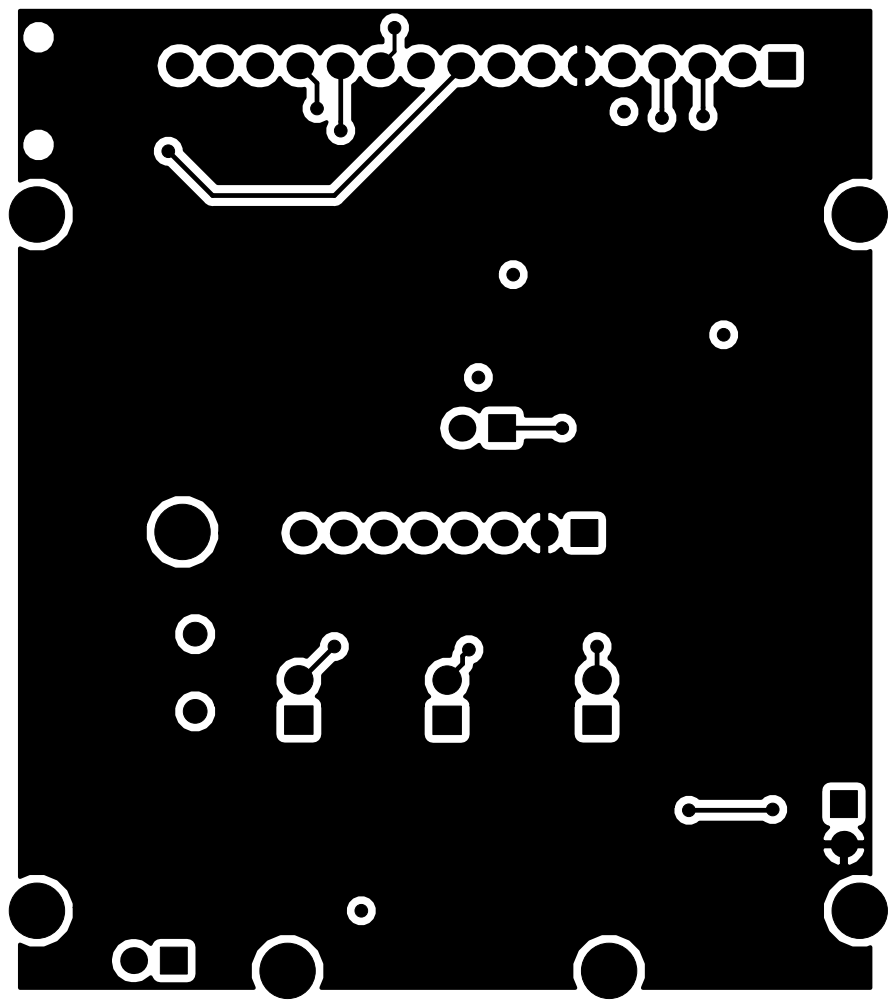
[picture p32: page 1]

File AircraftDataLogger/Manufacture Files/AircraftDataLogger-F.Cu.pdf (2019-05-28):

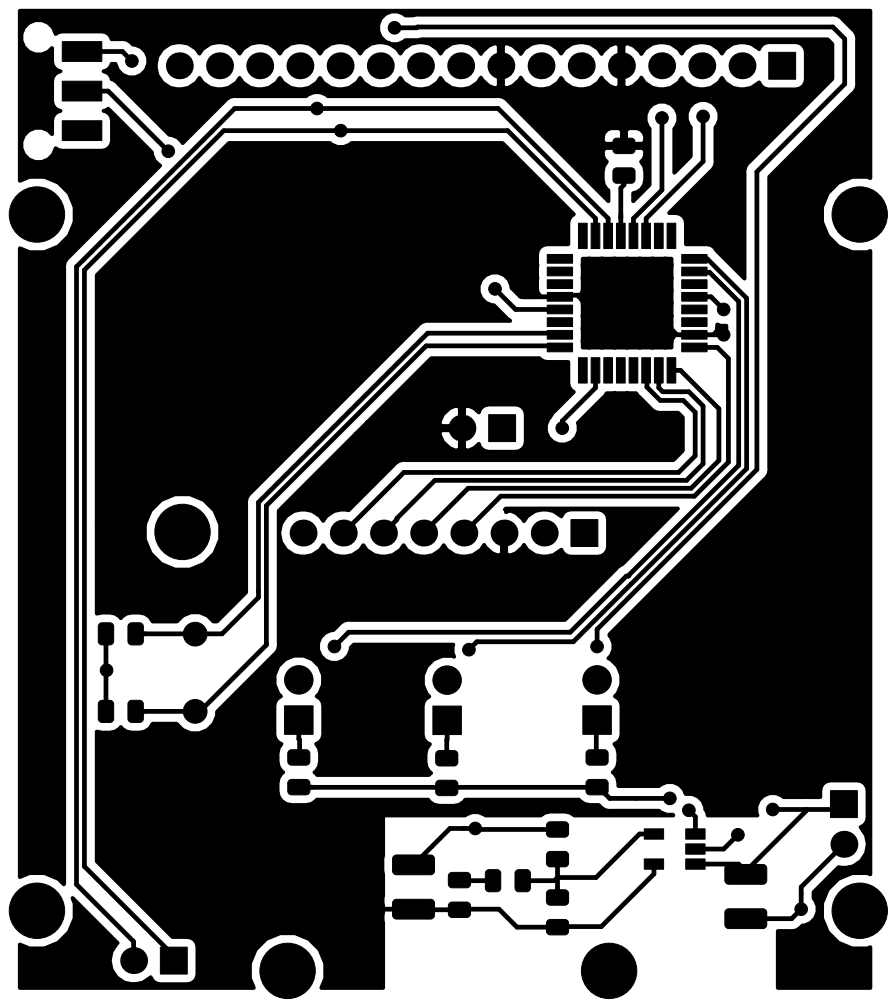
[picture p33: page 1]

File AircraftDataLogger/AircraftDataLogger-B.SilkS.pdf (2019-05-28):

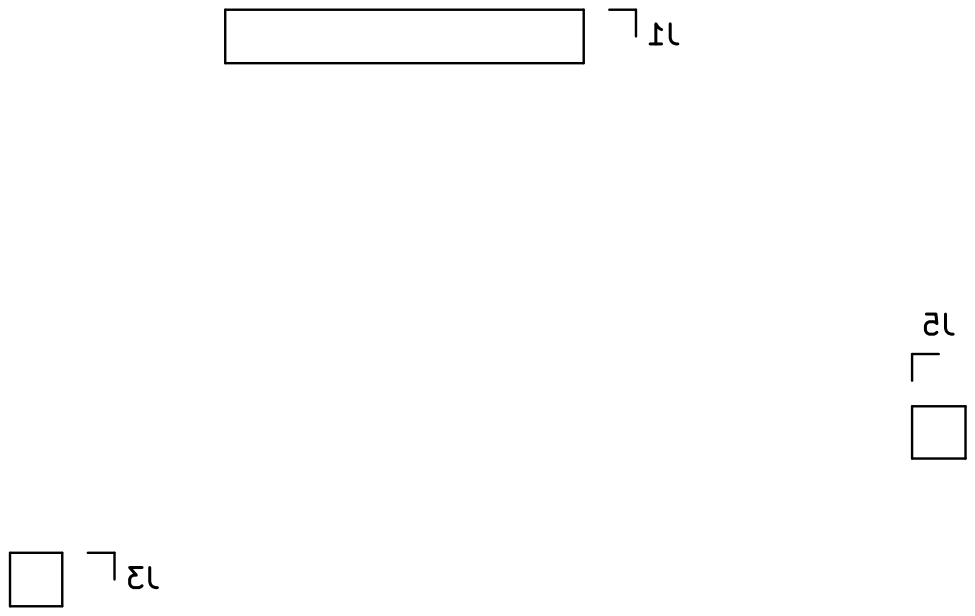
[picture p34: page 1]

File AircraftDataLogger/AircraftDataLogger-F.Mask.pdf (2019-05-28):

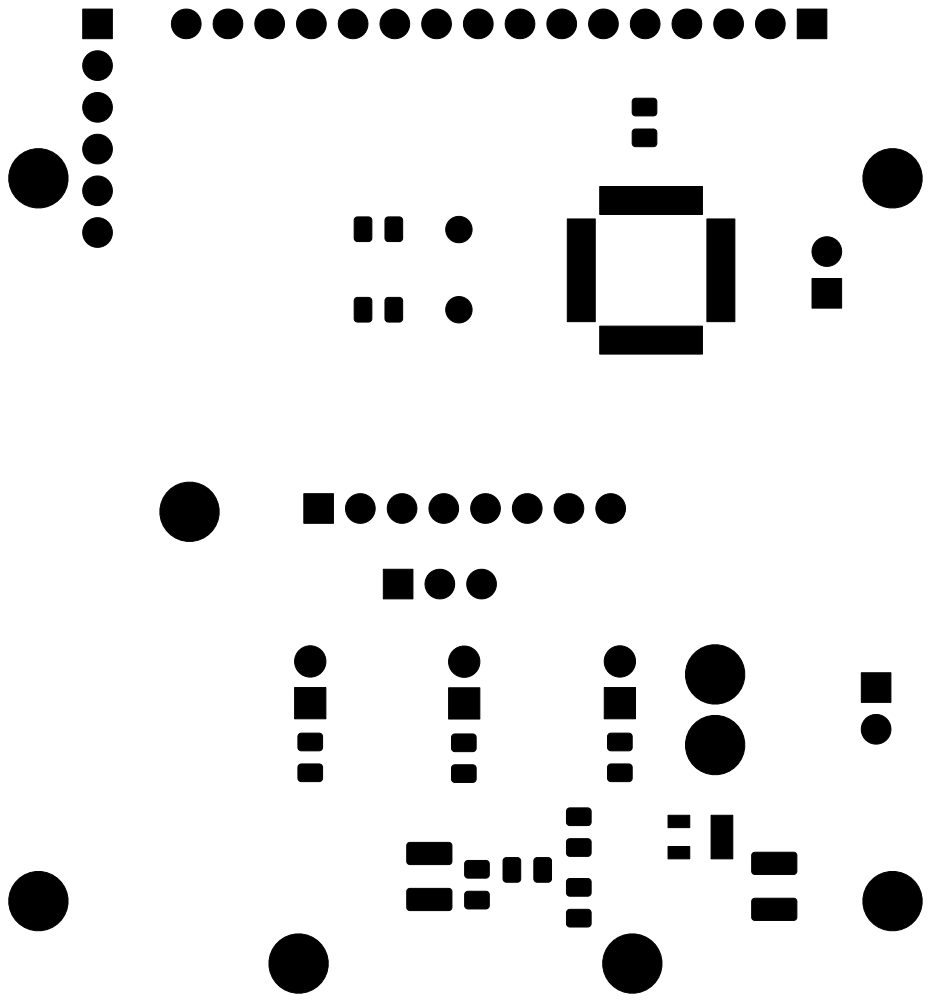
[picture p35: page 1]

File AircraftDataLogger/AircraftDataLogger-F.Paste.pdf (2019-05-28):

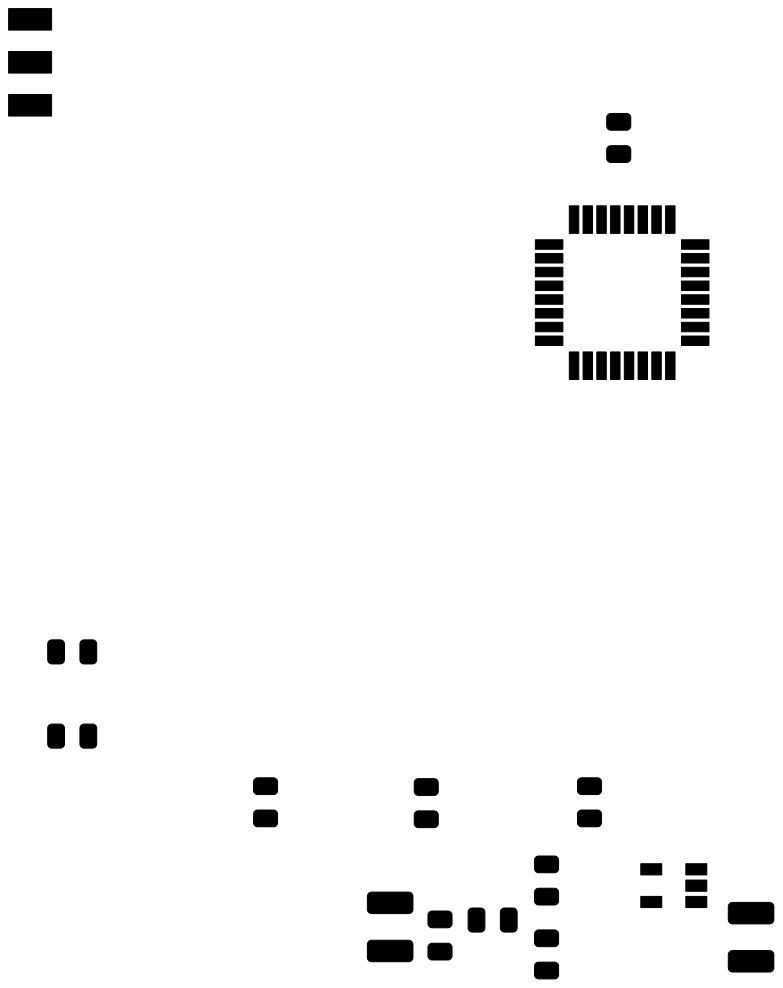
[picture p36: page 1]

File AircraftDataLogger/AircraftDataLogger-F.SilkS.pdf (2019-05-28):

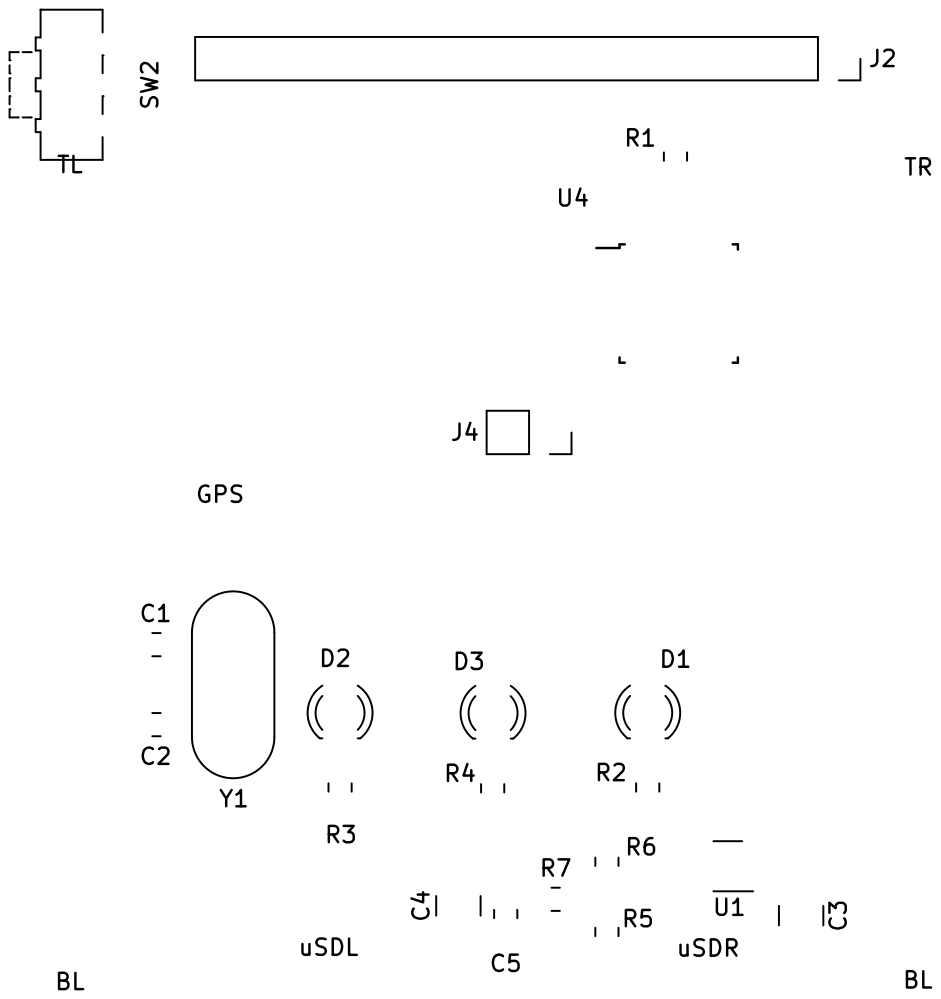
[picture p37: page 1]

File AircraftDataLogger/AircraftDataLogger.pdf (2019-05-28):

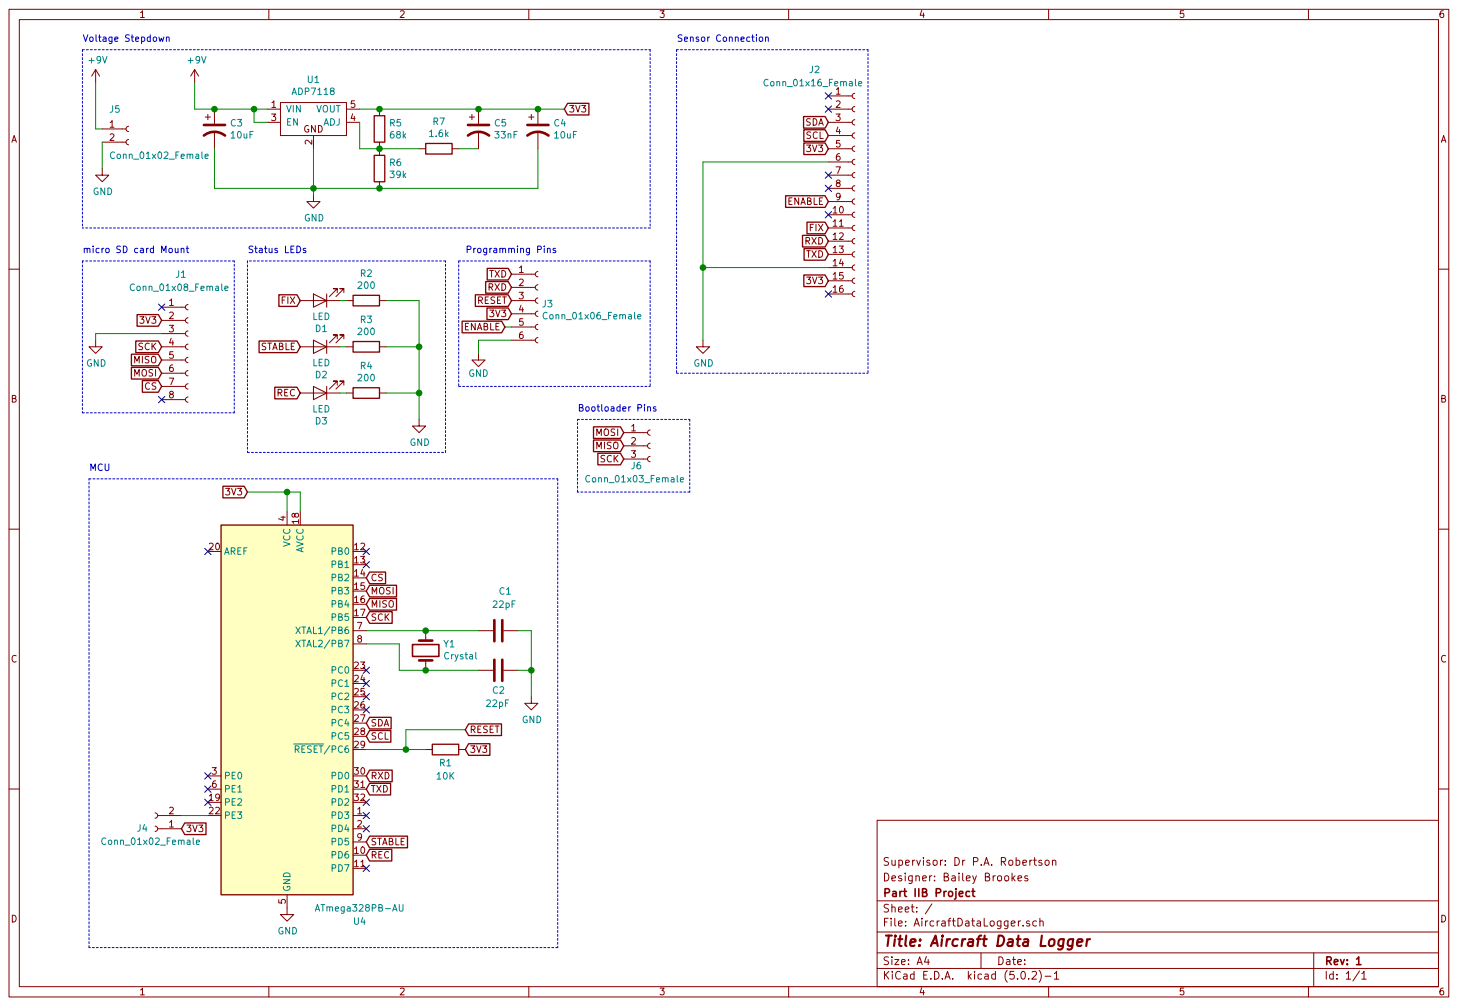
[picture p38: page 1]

SCK MISO MOSI CS

Designer: Bailey Brookes
File: AircraftDataLogger.sch Sheet: / Part IIB Project

Id: 1/1 Title: Aircraft Data Logger

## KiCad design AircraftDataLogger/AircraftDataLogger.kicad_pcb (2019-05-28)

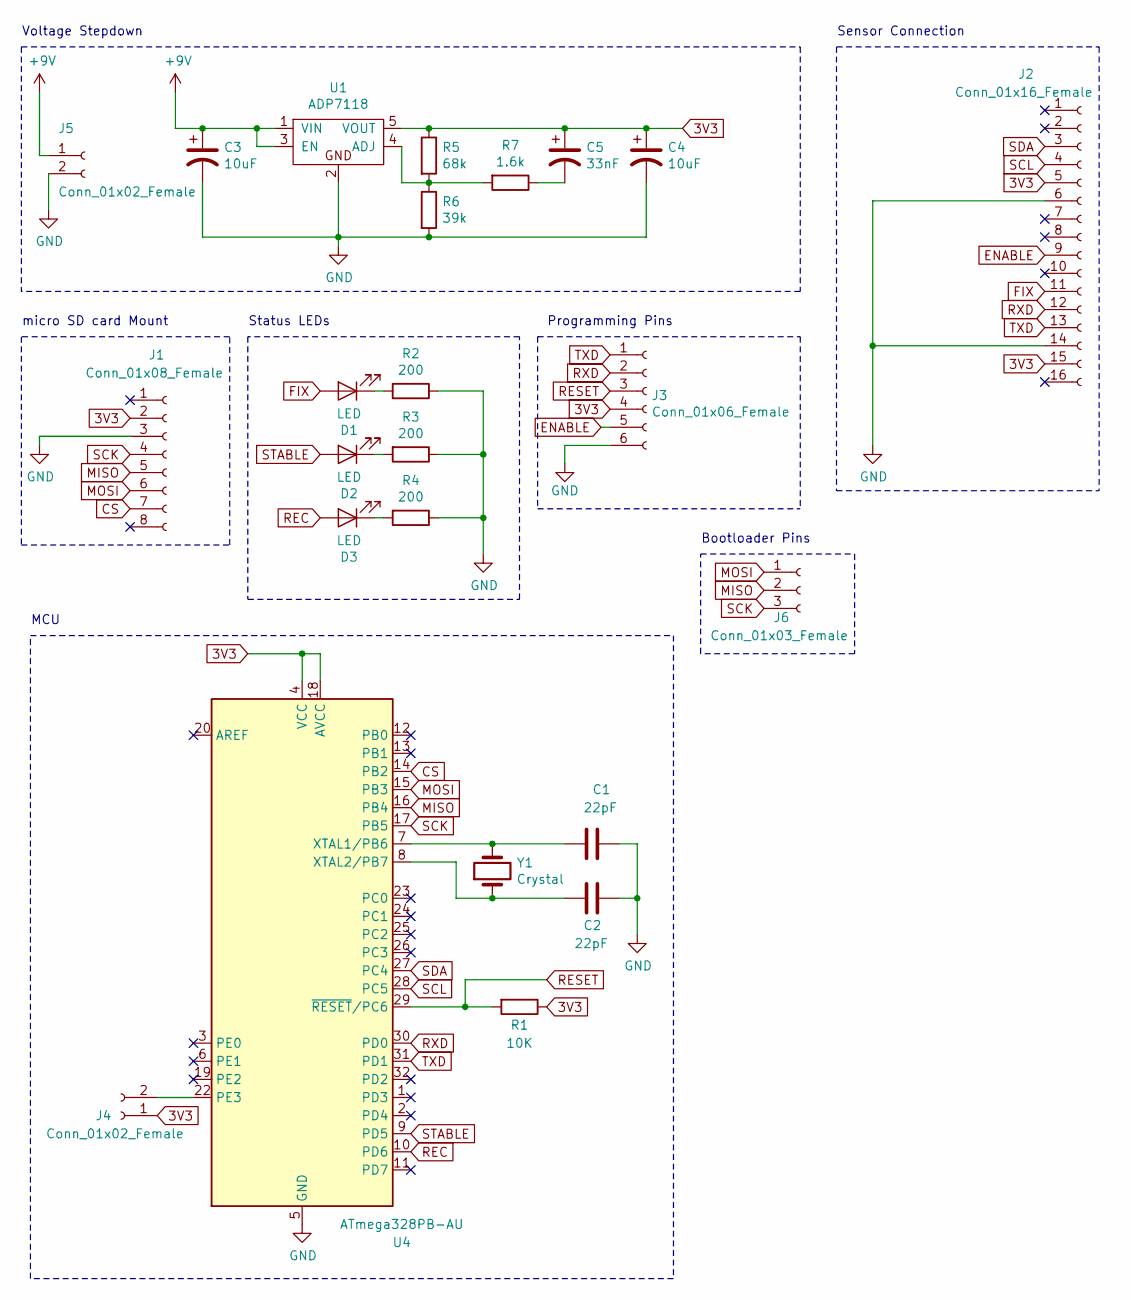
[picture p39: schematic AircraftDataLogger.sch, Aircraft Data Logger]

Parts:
C1, C2: 22pF; C_0805_2012Metric
C3, C4: 10uF; C_1210_3225Metric
C5: 33nF; C_0805_2012Metric
D1, D2, D3: LED; LED_D3.0mm_Clear
J1: Conn_01x08_Female; PinSocket_1x08_P2.54mm_Vertical
J2: Conn_01x16_Female; PinSocket_1x16_P2.54mm_Vertical
J3: Conn_01x06_Female; PinSocket_1x06_P2.54mm_Vertical
J4, J5: Conn_01x02_Female; PinSocket_1x02_P2.54mm_Vertical
J6: Conn_01x03_Female; PinSocket_1x03_P2.54mm_Vertical
R1: 10K; R_0805_2012Metric
R2, R3, R4: 200; R_0805_2012Metric
R5: 68k; R_0805_2012Metric
R6: 39k; R_0805_2012Metric
R7: 1.6k; R_0805_2012Metric
U1: ADP7118; TSOT-23-5
U4: ATmega328PB-AU; TQFP-32_7x7mm_P0.8mm
Y1: Crystal; Crystal_HC49-4H_Vertical

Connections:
3V3: C4.1, C5.1, J1.2, J2.5, J2.15, J3.4, J4.1, R1.1, R5.1, U1.5 (VOUT), U4.4 (VCC), U4.18 (AVCC)
+9V: C3.1, J5.1, U1.1 (VIN), U1.3 (EN)
CS: J1.7, U4.14 (PB2)
ENABLE: J2.9, J3.5
FIX: D1.2 (A), J2.11
GND: C1.1, C2.1, C3.2, C4.2, J1.3, J2.6, J2.14, J3.6, J5.2, R2.1, R3.1, R4.1, R6.2, U1.2, U4.5 (GND), U4.21 (GND)
MISO: J1.5, J6.2, U4.16 (PB4)
MOSI: J1.6, J6.1, U4.15 (PB3)
unnamed: C1.2, U4.7 (XTAL1/PB6), Y1.2
unnamed: C2.2, U4.8 (XTAL2/PB7), Y1.1
unnamed: C5.2, R7.1
unnamed: D1.1 (K), R2.2
unnamed: D2.1 (K), R3.2
unnamed: D3.1 (K), R4.2
unnamed: J4.2, U4.22 (PE3)
unnamed: R5.2, R6.1, R7.2, U1.4 (ADJ)
REC: D3.2 (A), U4.10 (PD6)
RESET: J3.3, R1.2, U4.29 (~RESET~/PC6)
RXD: J2.12, J3.2, U4.30 (PD0)
SCK: J1.4, J6.3, U4.17 (PB5)
SCL: J2.4, U4.28 (PC5)
SDA: J2.3, U4.27 (PC4)
STABLE: D2.2 (A), U4.9 (PD5)
TXD: J2.13, J3.1, U4.31 (PD1)

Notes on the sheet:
Voltage Stepdown
Sensor Connection
Status LEDs
Programming Pins
micro SD card Mount
MCU
Bootloader Pins

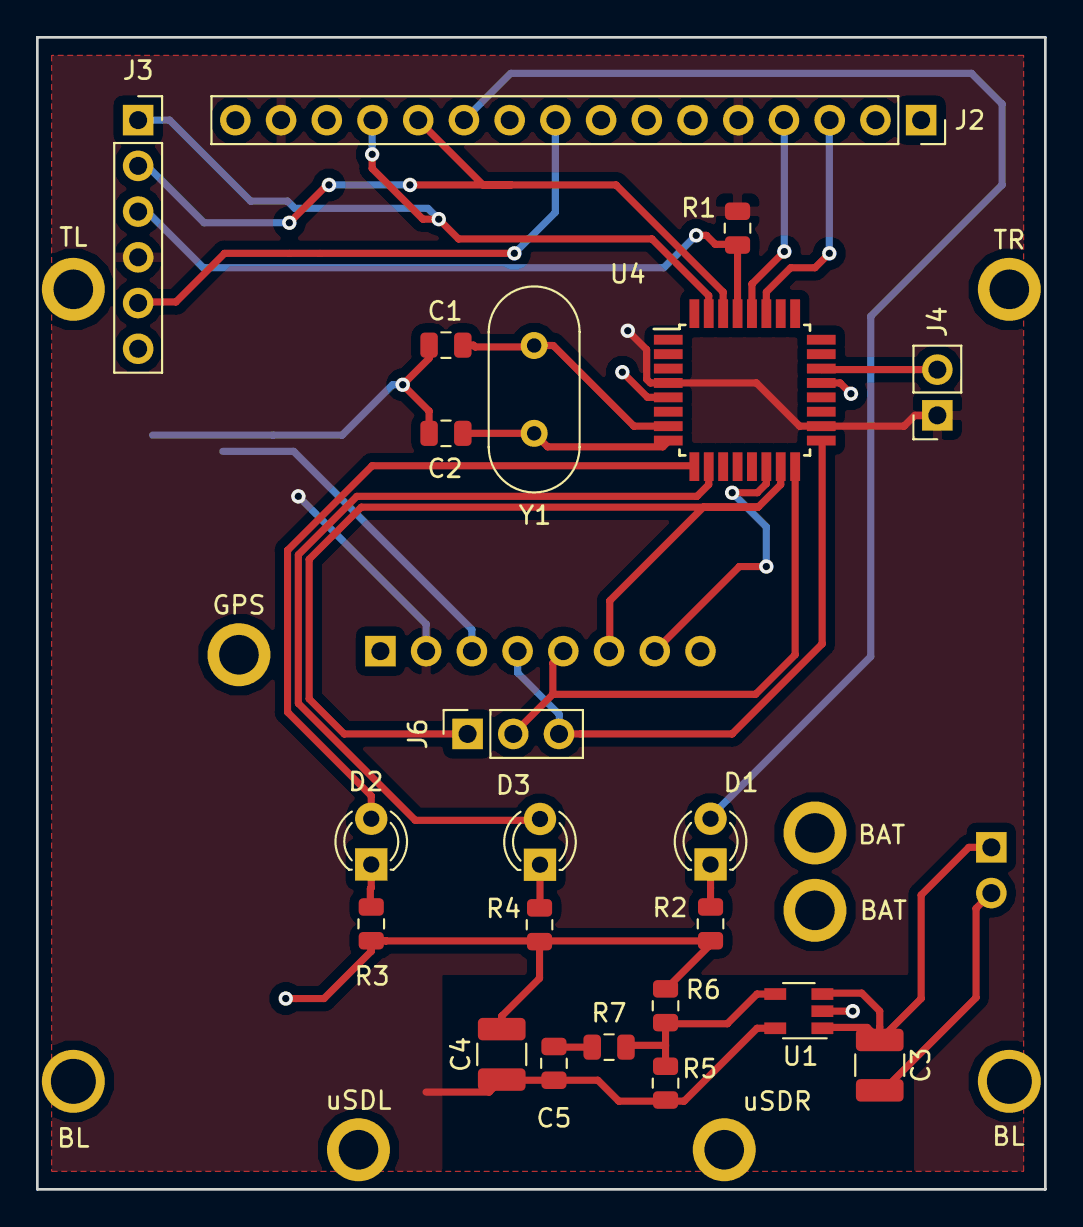
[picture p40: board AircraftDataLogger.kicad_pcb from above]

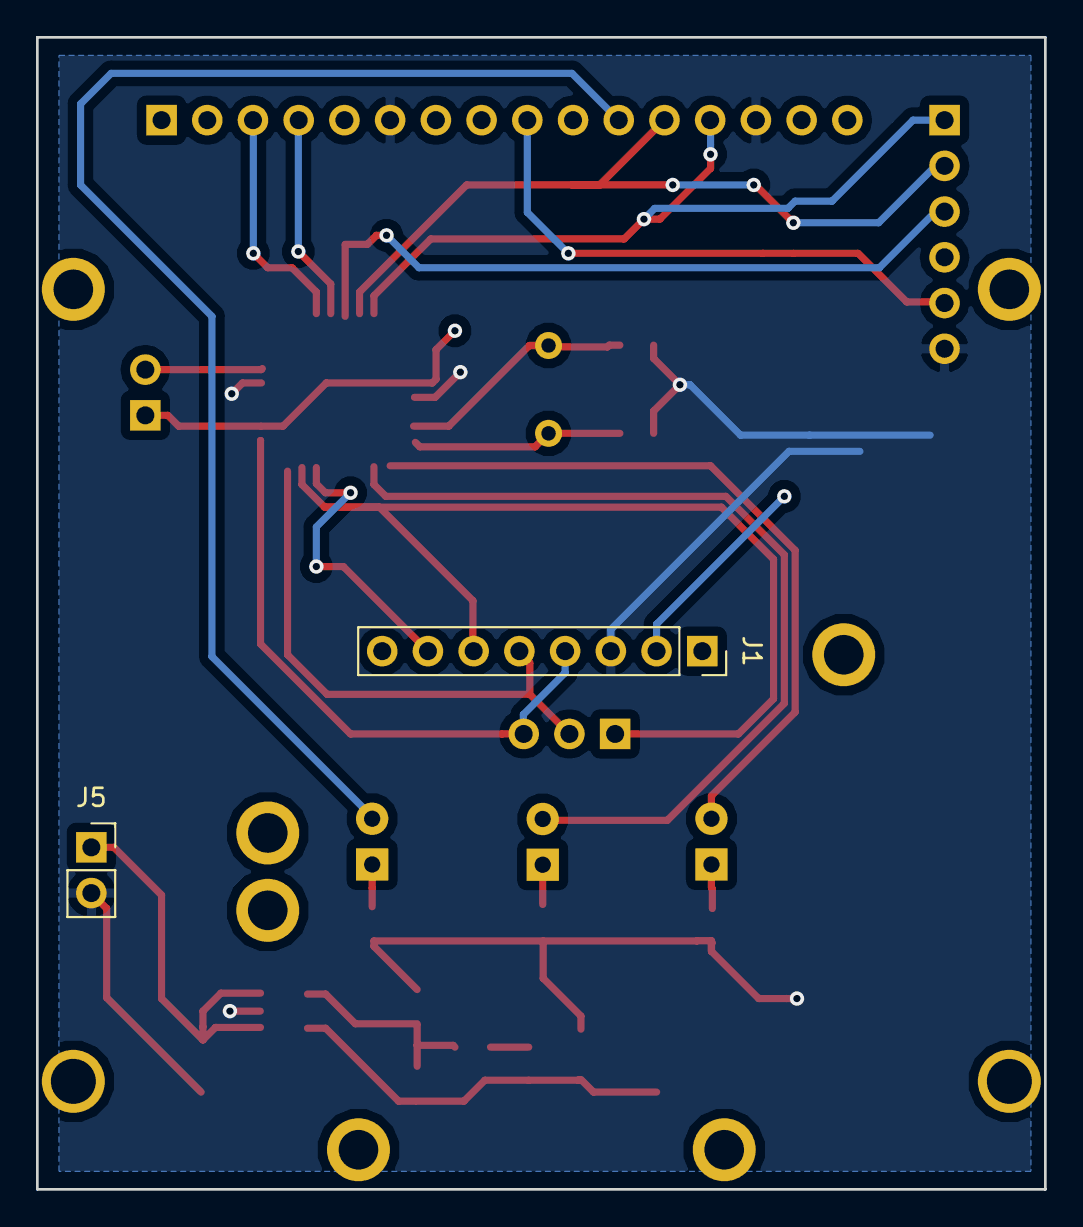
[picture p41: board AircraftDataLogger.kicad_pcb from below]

Board: 2 copper layers, 56.0 x 64.0 mm, 33 parts (2 on the bottom side), 24 nets.

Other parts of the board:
BAT: MountingHole_2.2mm_M2_ISO7380_Pad
BAT#2: MountingHole_2.2mm_M2_ISO7380_Pad
BL: MountingHole_2.2mm_M2_ISO7380_Pad
BL#2: MountingHole_2.2mm_M2_ISO7380_Pad
GPS: MountingHole_2.2mm_M2_ISO7380_Pad
TL: MountingHole_2.2mm_M2_ISO7380_Pad
TR: MountingHole_2.2mm_M2_ISO7380_Pad
uSDL: MountingHole_2.2mm_M2_ISO7380_Pad
uSDR: MountingHole_2.2mm_M2_ISO7380_Pad

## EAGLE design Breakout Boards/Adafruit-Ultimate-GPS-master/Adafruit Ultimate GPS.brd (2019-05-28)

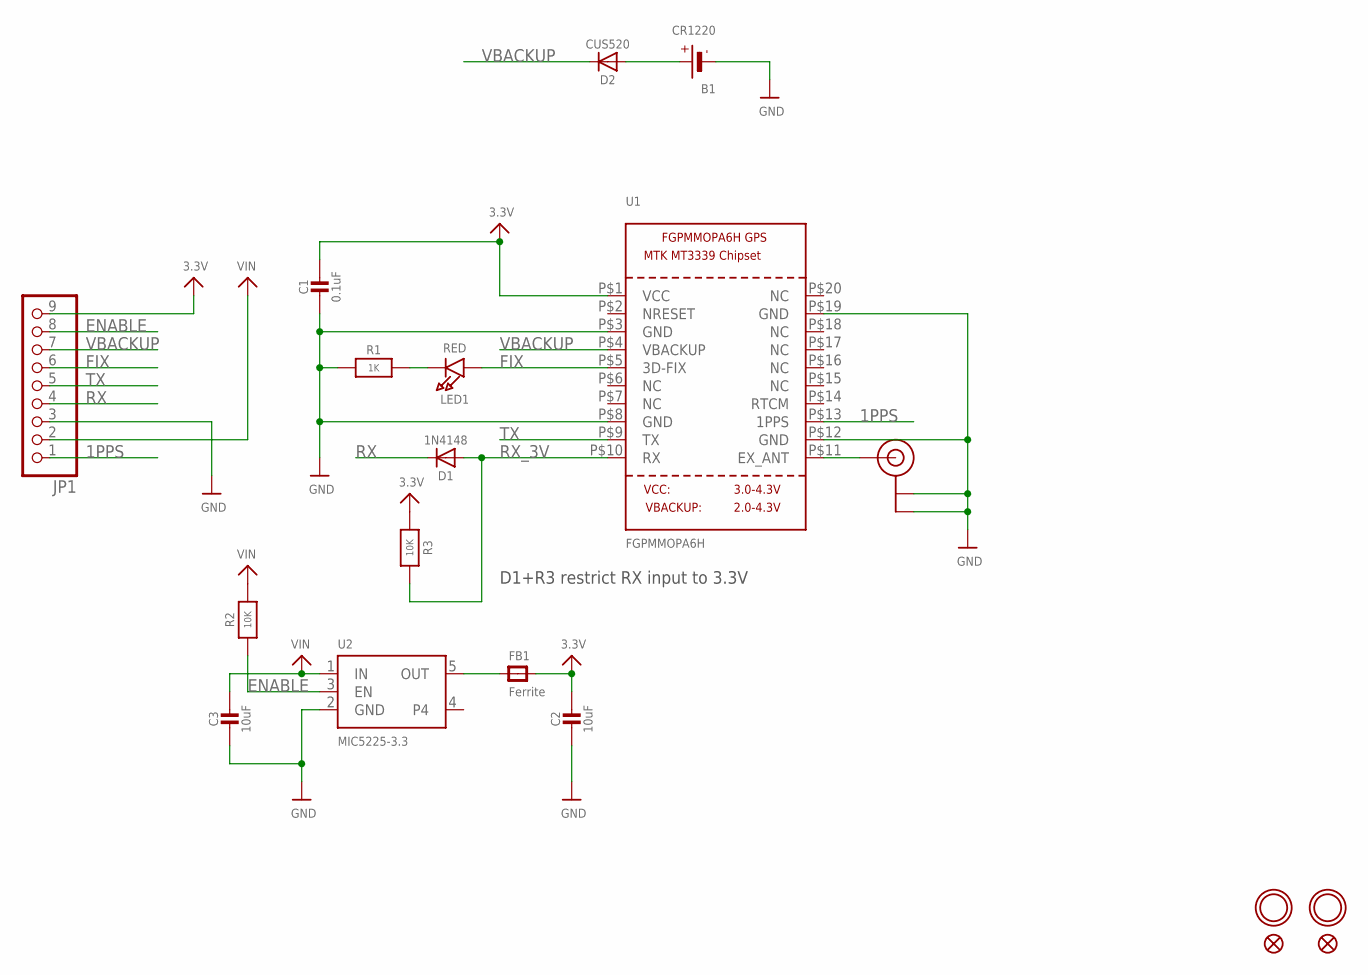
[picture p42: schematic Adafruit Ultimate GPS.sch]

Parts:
B1: CR1220
C1: 0.1uF; 0805-NO
C2, C3: 10uF; 0805-NO
D1: 1N4148; SOD-323
D2: CUS520; SOD-323
FB1: Ferrite; 0805-NO
FID1, FID2: FIDUCIAL""; FIDUCIAL_1MM
JP1: HEADER-1X970MIL; 1X09_ROUND_70
LED1: RED; CHIPLED_0805
R1: 1K; 0805-NO
R2, R3: 10K; 0805-NO
U1: FGPMMOPA6H
U2: MIC5225-3.3; SOT23-5
U$8, U$9: MOUNTINGHOLE2.5; MOUNTINGHOLE_2.5_PLATED
U$20: U.FL

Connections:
1PPS: JP1.1, U1.P$13 (1PPS)
3.3V: C1.1, C2.1, FB1.2, JP1.9, R3.1, U1.P$1 (VCC)
ENABLE: JP1.8, R2.1, U2.3 (EN)
FIX: JP1.6, LED1.A, U1.P$5 (3D-FIX)
GND: B1.-, C1.2, C2.2, C3.2, JP1.3, R1.1, U1.P$3 (GND), U1.P$8 (GND), U1.P$12 (GND), U1.P$19 (GND), U2.2 (GND), U$20.P$1 (GND), U$20.P$2 (GND)
unnamed: B1.+$1 (+), B1.+$2 (+), D2.A
unnamed: LED1.C, R1.2
unnamed: FB1.1, U2.5 (OUT)
unnamed: U1.P$11 (EX_ANT), U$20.P$3 (SIGNAL)
RX: D1.C, JP1.4
RX_3V: D1.A, R3.2, U1.P$10 (RX)
TX: JP1.5, U1.P$9 (TX)
VBACKUP: D2.C, JP1.7, U1.P$4 (VBACKUP)
VIN: C3.1, JP1.2, R2.2, U2.1 (IN)

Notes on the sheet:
D1+R3 restrict RX input to 3.3V

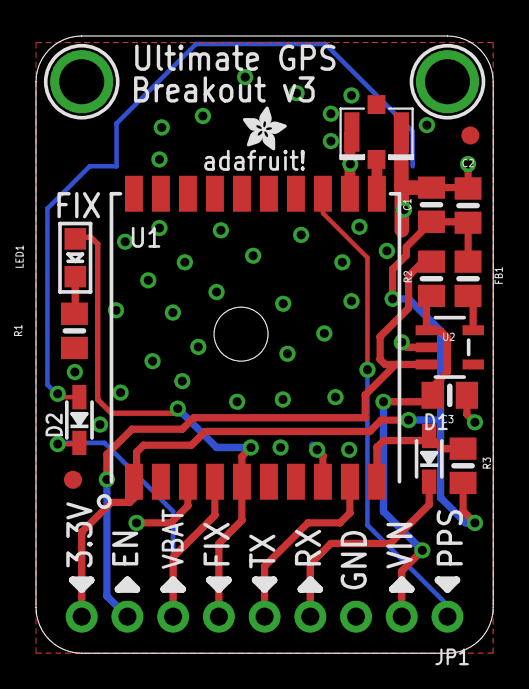
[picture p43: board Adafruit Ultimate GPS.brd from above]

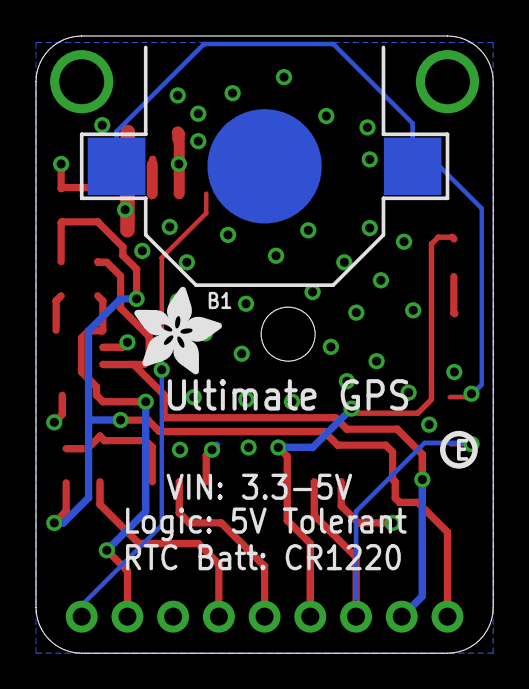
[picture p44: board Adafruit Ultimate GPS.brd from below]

Board: 2 copper layers, 25.4 x 34.3 mm, 22 parts (3 on the bottom side), 14 nets.

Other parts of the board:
U$15: ADAFRUIT_2.5MM
U$16: PCBFEAT-REV-040
U$18: ADAFRUIT_5MM

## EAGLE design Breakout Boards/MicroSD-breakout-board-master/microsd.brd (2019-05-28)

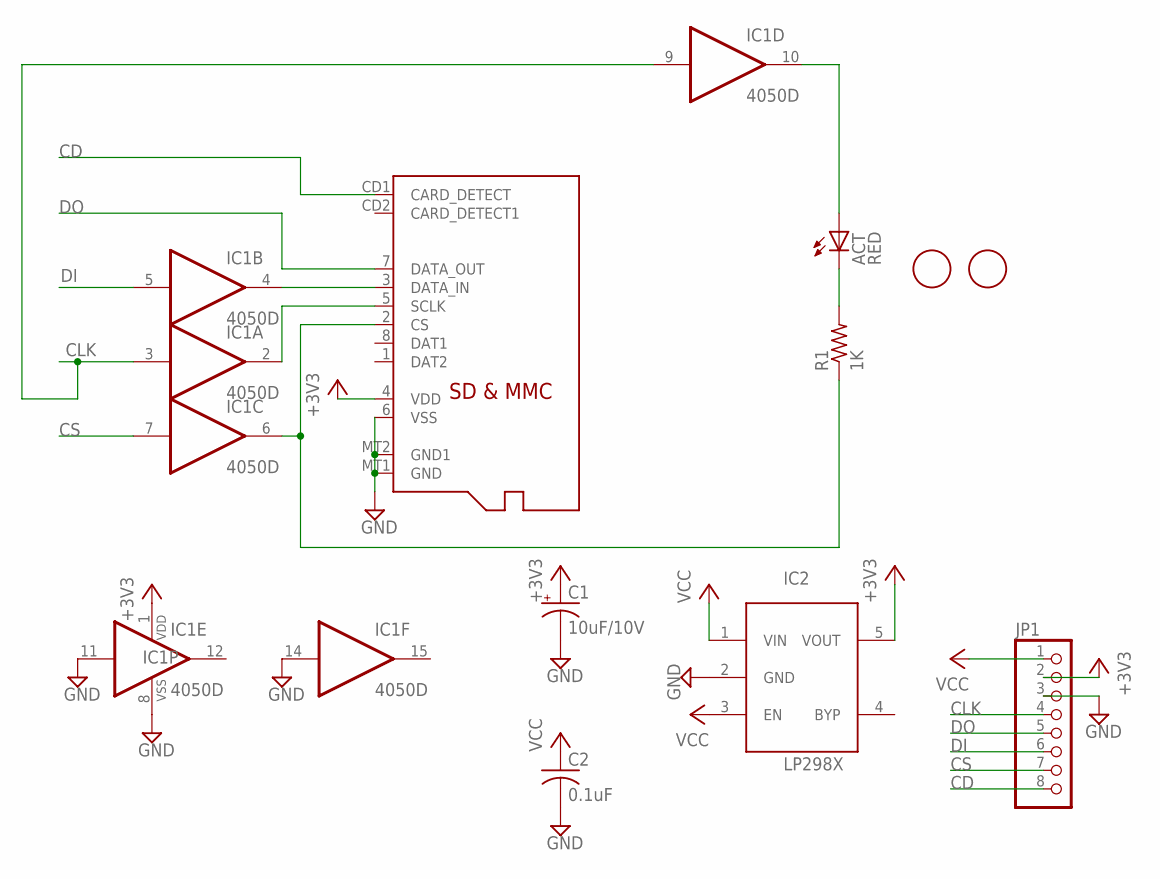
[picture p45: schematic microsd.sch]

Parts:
ACT: RED; CHIP-LED0805
C1: 10uF/10V; A/3216-18R
C2: 0.1uF; C0805K
IC1: 4050D; SO16
IC2: LP298XS; SOT23-5L
JP1: PINHD-1X8BIG; 1X08-BIG
R1: 1K; R0805
U$1, U$2: FIDUCIAL; FIDUCIAL_1MM
X1: MICROSD

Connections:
+3V3: C1.+, IC1.1 (VDD), IC2.5 (VOUT), JP1.2, X1.4 (VDD)
CD: JP1.8, X1.CD1 (CARD_DETECT)
CLK: IC1.3 (I), IC1.9 (I), JP1.4
CS: IC1.7 (I), JP1.7
DI: IC1.5 (I), JP1.6
DO: JP1.5, X1.7 (DATA_OUT)
GND: C1.-, C2.2, IC1.8 (VSS), IC1.11 (I), IC1.14 (I), IC2.2 (GND), JP1.3, X1.6 (VSS), X1.MT1 (GND), X1.MT2 (GND1)
unnamed: ACT.A, IC1.10 (O)
unnamed: IC1.2 (O), X1.5 (SCLK)
unnamed: IC1.6 (O), R1.1, X1.2 (CS)
unnamed: ACT.C, R1.2
unnamed: IC1.4 (O), X1.3 (DATA_IN)
VCC: C2.1, IC2.1 (VIN), IC2.3 (EN), JP1.1

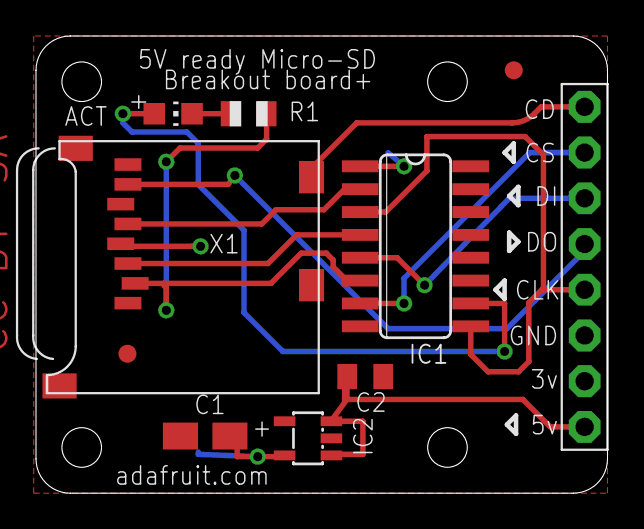
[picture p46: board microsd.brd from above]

Board: 2 copper layers, 31.8 x 25.4 mm, 10 parts (0 on the bottom side), 13 nets.

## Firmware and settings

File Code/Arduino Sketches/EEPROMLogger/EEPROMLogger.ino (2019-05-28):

#include <Wire.h>   // for IIC communication
#include <EEPROM.h> // To store the pressure data before logging to SD card
#include<SD.h>      // For logging
#include<SPI.h>
#include <Adafruit_GPS.h>
#include <SoftwareSerial.h>

#define STATUS     0x00
#define OUT_P_MSB  0x01
#define OUT_P_CSB  0x02
#define OUT_P_LSB  0x03
#define OUT_T_MSB  0x04
#define OUT_T_LSB  0x05
#define DR_STATUS  0x06
#define OUT_P_DELTA_MSB  0x07
#define OUT_P_DELTA_CSB  0x08
#define OUT_P_DELTA_LSB  0x09
#define OUT_T_DELTA_MSB  0x0A
#define OUT_T_DELTA_LSB  0x0B
#define WHO_AM_I   0x0C
#define F_STATUS   0x0D
#define F_DATA     0x0E
#define F_SETUP    0x0F
#define TIME_DLY   0x10
#define SYSMOD     0x11
#define INT_SOURCE 0x12
#define PT_DATA_CFG 0x13
#define BAR_IN_MSB 0x14
#define BAR_IN_LSB 0x15
#define P_TGT_MSB  0x16
#define P_TGT_LSB  0x17
#define T_TGT      0x18
#define P_WND_MSB  0x19
#define P_WND_LSB  0x1A
#define T_WND      0x1B
#define P_MIN_MSB  0x1C
#define P_MIN_CSB  0x1D
#define P_MIN_LSB  0x1E
#define T_MIN_MSB  0x1F
#define T_MIN_LSB  0x20
#define P_MAX_MSB  0x21
#define P_MAX_CSB  0x22
#define P_MAX_LSB  0x23
#define T_MAX_MSB  0x24
#define T_MAX_LSB  0x25
#define CTRL_REG1  0x26
#define CTRL_REG2  0x27
#define CTRL_REG3  0x28
#define CTRL_REG4  0x29
#define CTRL_REG5  0x2A
#define OFF_P      0x2B
#define OFF_T      0x2C
#define OFF_H      0x2D
#define MPL3115A2_ADDRESS 0x60 // 7-bit I2C address

SoftwareSerial mySerial(3,2);
Adafruit_GPS GPS(&mySerial);

// Global variables
String NMEA1;
String NMEA2;
char c;      
float deg;
float degWhole;
float degDec;
long startTime;
int addr = 0;
int chipSelect = 10; 

File mySensorData;

void setup()
{
  Wire.begin();
  Serial.begin(9600);
  SD.begin(chipSelect);
  GPS.begin(9600);
  GPS.sendCommand("$PGCMD,33,0*6D");
  GPS.sendCommand(PMTK_SET_NMEA_OUTPUT_RMCGGA);
  GPS.sendCommand(PMTK_SET_NMEA_UPDATE_1HZ);      // 1Hz update rate
  delay(1000); 

  /*if(IIC_Read(WHO_AM_I) == 196) 
    Serial.println("MPL3115A2 online!");
  else
    Serial.println("No response - check connections");*/

  // Configure the sensor
  setModeAltimeter(); // Measure altitude above sea level in meters
  //setModeBarometer(); // Measure pressure in Pascals from 20 to 110 kPa

  setOversampleRate(7); // Set Oversample to the recommended 128
  enableEventFlags(); // Enable all three pressure and temp event flags
}

void loop()
{
  readGPS();
  mySensorData = SD.open("NMEA4.txt", FILE_WRITE);
  mySensorData.println(NMEA1);
  mySensorData.println(NMEA2);
  mySensorData.close();

  float altitude = readAltitude();
  ///Serial.print("Altitude(m):");
  //Serial.print(altitude, 2);
  //Serial.println(",");

  EEPROM.put(addr, altitude);
  addr += sizeof(float);

  if(addr == EEPROM.length())
  {
    Serial.println("Readings from EEPROM");
    addr = 0;
    mySensorData= SD.open("Pressure.txt", FILE_WRITE);
    while(addr != EEPROM.length())
    {
        mySensorData.print(altitude);
        mySensorData.println(",");
        EEPROM.get(addr, altitude);
        //Serial.println(altitude);
        addr += sizeof(float);
    }
    mySensorData.close();
    //Serial.println("Readings end");
    addr = 0;
  }
  //delay(1000);
}

//Returns the number of meters above sea level
float readAltitude()
{
  toggleOneShot(); //Toggle the OST bit causing the sensor to immediately take another reading

  //Wait for PDR bit, indicates we have new pressure data
  int counter = 0;
  while( (IIC_Read(STATUS) & (1<<1)) == 0)
  {
      if(++counter > 100) return(-999); //Error out
      delay(1);
  }
  
  // Read pressure registers
  Wire.beginTransmission(MPL3115A2_ADDRESS);
  Wire.write(OUT_P_MSB);  // Address of data to get
  Wire.endTransmission(false); // Send data to I2C dev with option for a repeated start. THIS IS NECESSARY and not supported before Arduino V1.0.1!
  Wire.requestFrom(MPL3115A2_ADDRESS, 3); // Request three bytes

  //Wait for data to become available
  counter = 0;
  while(Wire.available() < 3)
  {
    if(counter++ > 100) return(-999); //Error out
    delay(1);
  }

  byte msb, csb, lsb;
  msb = Wire.read();
  csb = Wire.read();
  lsb = Wire.read();

  toggleOneShot(); //Toggle the OST bit causing the sensor to immediately take another reading

  // The least significant bytes l_altitude and l_temp are 4-bit,
  // fractional values, so you must cast the calulation in (float),
  // shift the value over 4 spots to the right and divide by 16 (since 
  // there are 16 values in 4-bits). 
  float tempcsb = (lsb>>4)/16.0;

  float altitude = (float)( (msb << 8) | csb) + tempcsb;

  return(altitude);
}

//Returns the number of feet above sea level
float readAltitudeFt()
{
  return(readAltitude() * 3.28084);
}

//Reads the current pressure in Pa
//Unit must be set in barometric pressure mode
float readPressure()
{
  toggleOneShot(); //Toggle the OST bit causing the sensor to immediately take another reading

  //Wait for PDR bit, indicates we have new pressure data
  int counter = 0;
  while( (IIC_Read(STATUS) & (1<<2)) == 0)
  {
      if(++counter > 100) return(-999); //Error out
      delay(1);
  }

  // Read pressure registers
  Wire.beginTransmission(MPL3115A2_ADDRESS);
  Wire.write(OUT_P_MSB);  // Address of data to get
  Wire.endTransmission(false); // Send data to I2C dev with option for a repeated start. THIS IS NECESSARY and not supported before Arduino V1.0.1!
  Wire.requestFrom(MPL3115A2_ADDRESS, 3); // Request three bytes

  //Wait for data to become available
  counter = 0;
  while(Wire.available() < 3)
  {
    if(counter++ > 100) return(-999); //Error out
    delay(1);
  }

  byte msb, csb, lsb;
  msb = Wire.read();
  csb = Wire.read();
  lsb = Wire.read();

  toggleOneShot(); //Toggle the OST bit causing the sensor to immediately take another reading

  // Pressure comes back as a left shifted 20 bit number
  long pressure_whole = (long)msb<<16 | (long)csb<<8 | (long)lsb;
  pressure_whole >>= 6; //Pressure is an 18 bit number with 2 bits of decimal. Get rid of decimal portion.

  lsb &= 0b00110000; //Bits 5/4 represent the fractional component
  lsb >>= 4; //Get it right aligned
  float pressure_decimal = (float)lsb/4.0; //Turn it into fraction

  float pressure = (float)pressure_whole + pressure_decimal;

  return(pressure);
}

float readTemp()
{
  toggleOneShot(); //Toggle the OST bit causing the sensor to immediately take another reading

  //Wait for TDR bit, indicates we have new temp data
  int counter = 0;
  while( (IIC_Read(STATUS) & (1<<1)) == 0)
  {
      if(++counter > 100) return(-999); //Error out
      delay(1);
  }
  
  // Read temperature registers
  Wire.beginTransmission(MPL3115A2_ADDRESS);
  Wire.write(OUT_T_MSB);  // Address of data to get
  Wire.endTransmission(false); // Send data to I2C dev with option for a repeated start. THIS IS NECESSARY and not supported before Arduino V1.0.1!
  Wire.requestFrom(MPL3115A2_ADDRESS, 2); // Request two bytes

  //Wait for data to become available
  counter = 0;
  while(Wire.available() < 2)
  {
    if(++counter > 100) return(-999); //Error out
    delay(1);
  }

  byte msb, lsb;
  msb = Wire.read();
  lsb = Wire.read();
  
  // The least significant bytes l_altitude and l_temp are 4-bit,
  // fractional values, so you must cast the calulation in (float),
  // shift the value over 4 spots to the right and divide by 16 (since 
  // there are 16 values in 4-bits). 
  float templsb = (lsb>>4)/16.0; //temp, fraction of a degree

  float temperature = (float)(msb + templsb);

  return(temperature);
}

//Give me temperature in fahrenheit!
float readTempF()
{
  return((readTemp() * 9.0)/ 5.0 + 32.0); // Convert celsius to fahrenheit
}

//Sets the mode to Barometer
//CTRL_REG1, ALT bit
void setModeBarometer()
{
  byte tempSetting = IIC_Read(CTRL_REG1); //Read current settings
  tempSetting &= ~(1<<7); //Clear ALT bit
  IIC_Write(CTRL_REG1, tempSetting);
}

//Sets the mode to Altimeter
//CTRL_REG1, ALT bit
void setModeAltimeter()
{
  byte tempSetting = IIC_Read(CTRL_REG1); //Read current settings
  tempSetting |= (1<<7); //Set ALT bit
  IIC_Write(CTRL_REG1, tempSetting);
}

//Puts the sensor in standby mode
//This is needed so that we can modify the major control registers
void setModeStandby()
{
  byte tempSetting = IIC_Read(CTRL_REG1); //Read current settings
  tempSetting &= ~(1<<0); //Clear SBYB bit for Standby mode
  IIC_Write(CTRL_REG1, tempSetting);
}

//Puts the sensor in active mode
//This is needed so that we can modify the major control registers
void setModeActive()
{
  byte tempSetting = IIC_Read(CTRL_REG1); //Read current settings
  tempSetting |= (1<<0); //Set SBYB bit for Active mode
  IIC_Write(CTRL_REG1, tempSetting);
}

//Setup FIFO mode to one of three modes. See page 26, table 31
//From user jr4284
void setFIFOMode(byte f_Mode)
{
  if (f_Mode > 3) f_Mode = 3; // FIFO value cannot exceed 3.
  f_Mode <<= 6; // Shift FIFO byte left 6 to put it in bits 6, 7.

  byte tempSetting = IIC_Read(F_SETUP); //Read current settings
  tempSetting &= ~(3<<6); // clear bits 6, 7
  tempSetting |= f_Mode; //Mask in new FIFO bits
  IIC_Write(F_SETUP, tempSetting);
}

//Call with a rate from 0 to 7. See page 33 for table of ratios.
//Sets the over sample rate. Datasheet calls for 128 but you can set it 
//from 1 to 128 samples. The higher the oversample rate the greater
//the time between data samples.
void setOversampleRate(byte sampleRate)
{
  if(sampleRate > 7) sampleRate = 7; //OS cannot be larger than 0b.0111
  sampleRate <<= 3; //Align it for the CTRL_REG1 register

  byte tempSetting = IIC_Read(CTRL_REG1); //Read current settings
  tempSetting &= 0b11000111; //Clear out old OS bits
  tempSetting |= sampleRate; //Mask in new OS bits
  IIC_Write(CTRL_REG1, tempSetting);
}

//Clears then sets the OST bit which causes the sensor to immediately take another reading
//Needed to sample faster than 1Hz
void toggleOneShot(void)
{
  byte tempSetting = IIC_Read(CTRL_REG1); //Read current settings
  tempSetting &= ~(1<<1); //Clear OST bit
  IIC_Write(CTRL_REG1, tempSetting);

  tempSetting = IIC_Read(CTRL_REG1); //Read current settings to be safe
  tempSetting |= (1<<1); //Set OST bit
  IIC_Write(CTRL_REG1, tempSetting);
}

//Enables the pressure and temp measurement event flags so that we can
//test against them. This is recommended in datasheet during setup.
void enableEventFlags()
{
  IIC_Write(PT_DATA_CFG, 0x07); // Enable all three pressure and temp event flags 
}

// These are the two I2C functions in this sketch.
byte IIC_Read(byte regAddr)
{
  // This function reads one byte over IIC
  Wire.beginTransmission(MPL3115A2_ADDRESS);
  Wire.write(regAddr);  // Address of CTRL_REG1
  Wire.endTransmission(false); // Send data to I2C dev with option for a repeated start. THIS IS NECESSARY and not supported before Arduino V1.0.1!
  Wire.requestFrom(MPL3115A2_ADDRESS, 1); // Request the data...
  return Wire.read();
}

void IIC_Write(byte regAddr, byte value)
{
  // This function writes one byto over IIC
  Wire.beginTransmission(MPL3115A2_ADDRESS);
  Wire.write(regAddr);
  Wire.write(value);
  Wire.endTransmission(true);
}

void readGPS()
{  
    clearGPS();

    while(!GPS.newNMEAreceived())
    {
        c=GPS.read();
    }

    GPS.parse(GPS.lastNMEA());
    NMEA1=GPS.lastNMEA();

    while(!GPS.newNMEAreceived())
    {
        c=GPS.read();
    }
    GPS.parse(GPS.lastNMEA());
    NMEA2=GPS.lastNMEA();

    //Serial.println(NMEA1);
    //Serial.println(NMEA2);
    //Serial.println("");
}

void clearGPS() 
{  
    while(!GPS.newNMEAreceived())
    {
        c=GPS.read();
    }
    GPS.parse(GPS.lastNMEA());
  
    while(!GPS.newNMEAreceived())
    {
        c=GPS.read();
    }
    GPS.parse(GPS.lastNMEA());

    while(!GPS.newNMEAreceived())
    {
        c=GPS.read();
    }
    GPS.parse(GPS.lastNMEA());
}

void convLong()
{
    degWhole=float(int(GPS.longitude / 100));

    degDec=(GPS.longitude - degWhole * 100 ) / 60;

    deg = degWhole + degDec;

    if(GPS.lon=='W')
    {
        deg = (-1) * deg;
    }
}

void convLati()
{
    degWhole=float(int(GPS.latitude / 100));

    degDec=(GPS.latitude - degWhole * 100 ) / 60;

    deg = degWhole + degDec;

    if(GPS.lat=='S')
    {
        deg = (-1) * deg;
    }
}

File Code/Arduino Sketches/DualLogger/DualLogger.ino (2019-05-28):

// Header files
#include <SD.h>
#include<SPI.h>
#include <Adafruit_GPS.h>
#include <SoftwareSerial.h>


// Set up GPS serial
SoftwareSerial mySerial(11,10);
Adafruit_GPS GPS(&mySerial);

// Global variables
long startTime;
String NMEA1;
String NMEA2;
char c;      
float deg;
float degWhole;
float degDec;
int chipSelect = 53; 
unsigned long time;
int AnalogPin = 3;
int SwitchValue = 0;         
bool FirstPastFlag = true;
char GPSFile;
char PressureFile;
File mySensorData;

 // Main body ----------------------------------------------------------
void setup()
{
    GPS.begin(9600);
    Serial.begin(9600);  // start serial for output
   // Serial1.begin(9600);
    GPS.sendCommand("$PGCMD,33,0*6D");
    GPS.sendCommand(PMTK_SET_NMEA_OUTPUT_RMCGGA);
    GPS.sendCommand(PMTK_SET_NMEA_UPDATE_1HZ);      // 1Hz update rate
    delay(1000); 
  
    SD.begin(chipSelect);
    pinMode(8,OUTPUT);
}

void loop()
{
    
    SwitchValue = analogRead(AnalogPin);     // read the input pin
    if(SwitchValue > 600) //Only save data if switch on
    {
        Serial.println("In if");
        if(FirstPastFlag == true)
        {
            GPSFile      = generateFiles("GPS");
            PressureFile = generateFiles("Alt");
            FirstPastFlag = false;
        }
        
        digitalWrite(8,HIGH);                               // Turn LED ON
        // Save GPS data to SD card
        readGPS();  
        mySensorData = SD.open(GPSFile, FILE_WRITE); 
        mySensorData.println(NMEA1);
        mySensorData.println(NMEA2);
        mySensorData.close();
    
    }
    else
    {
        digitalWrite(8,LOW);
        delay(2000);
        FirstPastFlag = true;
    }
}

// Function Defintions -------------------------------------------------
void readGPS() 
{ 
    Serial.println("Sentence 1");
    clearGPS();   
    while(!GPS.newNMEAreceived()) 
    {
        c=GPS.read();
        Serial.println(c);
    }
    GPS.parse(GPS.lastNMEA());
    NMEA1=GPS.lastNMEA();

    Serial.println("Sentence 2");
    while(!GPS.newNMEAreceived()) 
    {
    c=GPS.read();
    }
    GPS.parse(GPS.lastNMEA());
    NMEA2=GPS.lastNMEA();

    Serial.println(NMEA1);
    Serial.println(NMEA2);
}

void clearGPS() 
{  
    while(!GPS.newNMEAreceived()) 
    {
    c=GPS.read();
    }
    GPS.parse(GPS.lastNMEA());
  
    while(!GPS.newNMEAreceived()) 
    {
        c=GPS.read();
    }
  GPS.parse(GPS.lastNMEA());

    while(!GPS.newNMEAreceived()) 
    {
        c=GPS.read();
    }
    GPS.parse(GPS.lastNMEA());
}

char generateFiles(String sensor) 
{
    //derived from code found at http://forum.arduino.cc/index.php?topic=57460.0
    String fileName = String();
    String message = String();
    unsigned int filenumber = 1;
    while(!filenumber==0) 
    {
        fileName = sensor;
        fileName += filenumber;
        fileName += ".txt";
        message = fileName;
        char charFileName[fileName.length() + 1];
        fileName.toCharArray(charFileName, sizeof(charFileName));

        if (SD.exists(charFileName)) 
        { 
            message += " exists.";
            filenumber++;
        }
        else 
        {
            File dataFile = SD.open(charFileName, FILE_WRITE);
            message += " created.";
            dataFile.close();
            filenumber = 0;
            return charFileName;
        }
    }
}

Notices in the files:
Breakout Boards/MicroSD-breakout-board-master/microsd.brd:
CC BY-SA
